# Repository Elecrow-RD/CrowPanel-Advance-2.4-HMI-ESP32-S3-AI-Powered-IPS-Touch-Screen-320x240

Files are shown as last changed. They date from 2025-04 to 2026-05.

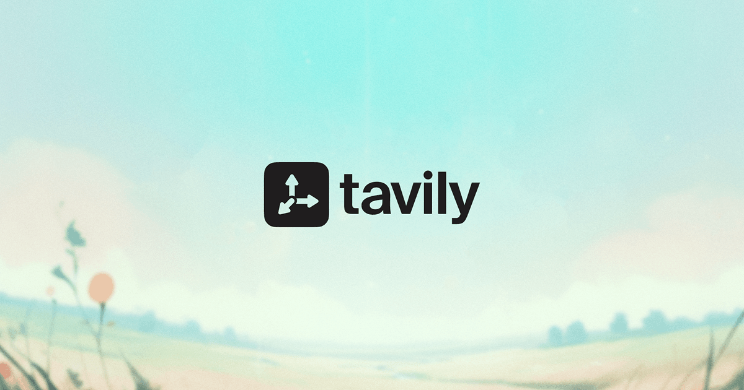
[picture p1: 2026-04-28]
example/V1.1_and_V1.2/Mimiclaw/mimiclaw/docs/tool-setup/images/tavily-og.png

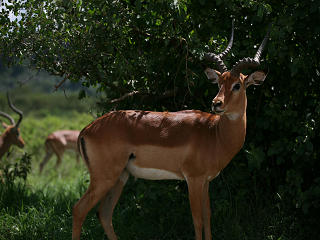
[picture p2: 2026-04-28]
example/V1.1_and_V1.2/ESP_IDF/Lesson05-SD_Images_24_28/picture_materials/2.bmp

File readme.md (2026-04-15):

## Menu
### 1, Product picture
### 2, Product version number
### 3, product information
### 4, Use the driver module
### 5,Quick Start
### 6,Folder structure.
### 7,Pin definition
### 8,Guidelines for downloading some of the files from the github repository

### 1, Product picture

ESP32 Advance HMI 2.4inch display

### 2, Product version number

| | Hardware | Software | Remark |
| ---- | --- | --- | --- |
| 1 | V1.0 | V1.0 | old |
| 1 | V1.1 | V1.1 | old |
| 1 | V1.2 | V1.2 | latest |

### Version update points:

**Version 1.1** 

V1.1 upgraded, optimized the amplifier circuit, better sound quality, and use IO21 to control mute. i2s_mic changed to two pins IO9 and IO10 control.

**Version 1.2** 

Only the button component has been updated. All other hardware and I/O pins remain the same as in the previous version.

### 3, product information

| Main Chip-**ESP32-S3-WROOM-1-N16R8** | |
| --- | --- |
| CPU/SoC | high-performance Xtensa 32-bit LX7 dual-core processor, with a  up to 240MHz |
| System Memory | 512KB SRAM、8M PSRAM |
| Memory | 16M Flash，384KB ROM |
| Development Language | MicroPython、C/C++ |
| Development Environment | ESP-IDF、Arduino IDE、LVGL、PlatformIO、MicroPython |
| **Screen** | |
| Size | 2.4 inch |
| Diver IC | ST7789 |
| Resolution | 800*480 |
| Display Panel | IPS Panel |
| Touch Panel | Capacitive Single Touch |
| Viewing Angle | 178° |
| Brightness | 400 cd/m²(Typ.) |
| Color Depth | 16-bit |
| **Wireless Communication - Onboard Antenna** | |
| WiFi | Support 2.4GHz, 802.11a/b/g/n |
| Bluetooth | Support Bluetooth 5.0 and BLE |
| Other | **Zigbee、nRF2401、Matter、Thread and Wi-Fi 6 (Optional)** |
| **Interface/Function** | |
| Interface | USB port, UART, I2C, SD card slot, battery socket, speaker port, microphone, etc. |
| Function | Audio amplifier, volume control, battery charge management, USB to UART, etc. |
| **Button/LED Indicator** | |
| Reset Button | Yes, press to reset device |
| Boot Button | Yes, press and hold the power button to burn the program |
| PWR | Power indicator |
| CHG | Lithium battery charging status, completion indication |
| **Other** | |
| Installation method | Back hanging, fixed hole |
| Operating temperature | -20~70 °C |
| Storage temperature | -30~80 °C |
| Power Input | 5V/2A, USB or UART terminal |
| Dimensions | 77.1*51.8*15.8*mm |

### 4, Use the driver module

| Name | dependency library |
| --- | --- |
| LVGL | lvgl/lvgl@8.3.3 |
| ST7789 | Adafruit GFX Library<br/>version=1.11.0 |

### 5,Quick Start

### Arduino IDE starts

#### Teaching Case Path：./example/example_code2.4

1.Download the library files used by this product to the 'libraries' folder.

C:\Users\Documents\Arduino\libraries\



2.Open the Arduino IDE



3.Open the code configuration environment and burn it



### ESP-IDF starts

#### Teaching Case Path：./example/idf_code

1.Right-click on an empty space in the project folder and select "Open with VS Code" to open the project.


2.In the IDF plug-in, select the port, then compile and flash


### 6,Folder structure.

|--3D file： Contains 3D model files (.stp) for the hardware. These files can be used for visualization, enclosure design, or integration into CAD software.

|--Datasheet: Includes datasheets for components used in the project, providing detailed specifications, electrical characteristics, and pin configurations.

|--Eagle_SCH&PCB: Contains **Eagle CAD** schematic (`.sch`) and PCB layout (`.brd`) files. These are used for circuit design and PCB manufacturing.

|--example: Provides example code and projects to demonstrate how to use the hardware and libraries. These examples help users get started quickly.

|--factory_firmware: Stores pre-compiled factory firmware that can be directly flashed onto the device. This ensures the device runs the default functionality.

|--factory_sourcecode:  Contains the source code for the factory firmware, allowing users to modify and rebuild the firmware as needed.

|--libraries: Includes necessary libraries required for compiling and running the project. These libraries provide drivers and additional functionalities for the hardware.

|--Squareline_studio Instructions for use: Squareline_studio instructions: Demonstrate the use of squareline studio.

### 7,Pin definition

#define SD_MOSI 6
#define SD_MISO 4
#define SD_SCK 5
#define SD_CS 7 

cfg.pin_sclk = 42;  // SPI、SCLK

cfg.pin_mosi = 39;  // SPI、CLK

cfg.pin_miso = -1;  // SPI、MISO

cfg.pin_dc = 41; 

#define TOUCH_GT911_SCL 16

#define TOUCH_GT911_SDA 15

### 8,Guidelines for downloading some of the files from the github repository

##### 1, open the link in your browser: https://downgit.github.io/

##### 2, paste the URL of the GitHub destination folder in the input box (example format: `https://github.com/username/repository name/tree/branch name/folder path`)

github_download1

##### 3, even a that way to download the file.

①Click the “Create Download Link” button to create a download link, copy the link and open it with your browser to download the contents of the corresponding folder directly.

github_download2

②Click Download, and you can also download it directly.

github_download3

#### Note: DownGit downloads are stored by default in **your browser's default downloads folder**, usually:

- **Windows**: `C:\Users\your username\Downloads\` (downloads folder)
- **macOS**: `~/Downloads/` (downloads folder)
- **Linux**: `~/Downloads/` (Downloads folder)

If you change the default download path in your browser, the file will be stored in the download location you set. You can find the downloaded file path in your browser's **Download History** (shortcut `Ctrl + J` or `Cmd + J`).

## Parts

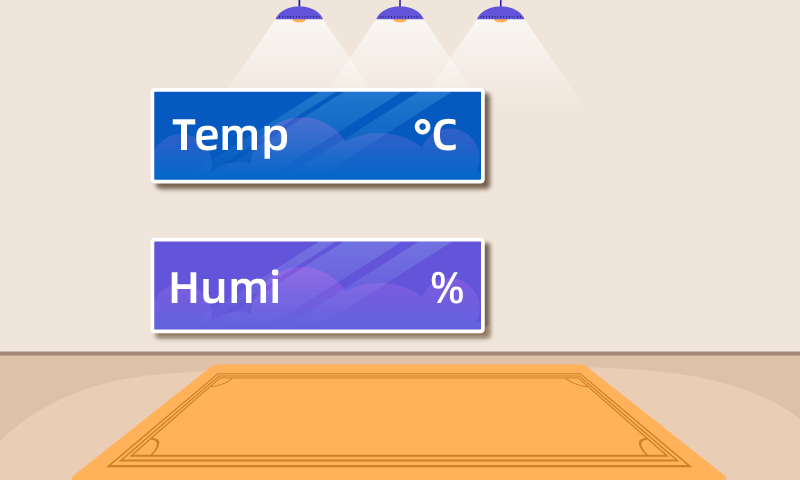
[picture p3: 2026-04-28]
example/V1.0/Arduino_Code/lesson-05/source material/800x480/background.png

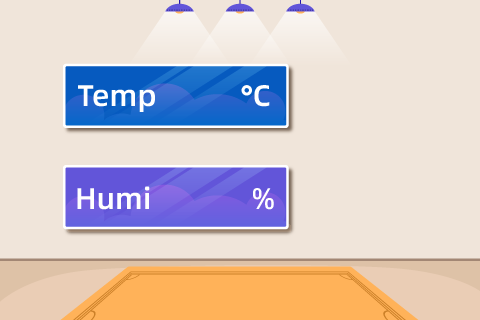
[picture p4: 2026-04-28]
example/V1.0/Arduino_Code/lesson-05/source material/480x320/background.png

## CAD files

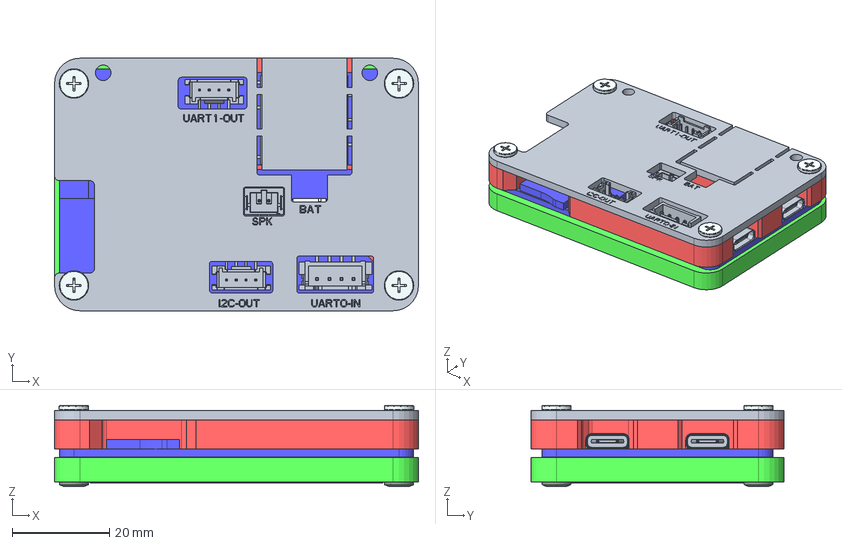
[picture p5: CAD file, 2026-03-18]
3D file/advance-hmi2_4-20260126.stp
74.8 x 51.9 x 16.7 mm
ESP32_DISPLAY_2_4_INCH_V1_0_15
GROVE_12_11
PRT0003_11
BOSS-EXTRUDE7_4__1_1_4_1_5
BOSS-EXTRUDE7_5__1_1_4_1_5
BOSS-EXTRUDE7_8__1_1_4_1_5
BOSS-EXTRUDE7_3__1_1_4_1_5
BOSS-EXTRUDE7_7__1_1_4_1_5
BOSS-EXTRUDE14_4__1_1_4_1_5
BOSS-EXTRUDE14_2__1_1_4_1_5
BOSS-EXTRUDE14_8__1_1_4_1_5
BOSS-EXTRUDE14_5__1_1_4_1_5
BOSS-EXTRUDE7_6__1_1_4_1_5
CUT-EXTRUDE5_1_1_4_1_5
MIRROR2_1_1_4_1_5
BOSS-EXTRUDE7_1__1_1_4_1_5
BOSS-EXTRUDE14_10__1_1_4_1_5
BOSS-EXTRUDE14_11__1_1_4_1_5
BOSS-EXTRUDE14_9__1_1_4_1_5
BOSS-EXTRUDE14_6__1_1_4_1_5
BOSS-EXTRUDE14_12__1_1_4_1_5
BOSS-EXTRUDE14_3__1_1_4_1_5
BOSS-EXTRUDE14_7__1_1_4_1_5
BOSS-EXTRUDE7_9__1_1_4_1_5
BOSS-EXTRUDE7_2__1_1_4_1_5
BOSS-EXTRUDE7_4__1_1_1_1_4_8_5
BOSS-EXTRUDE7_5__1_1_1_1_4_8_5
BOSS-EXTRUDE7_8__1_1_1_1_4_8_5
BOSS-EXTRUDE7_3__1_1_1_1_4_8_5
BOSS-EXTRUDE7_7__1_1_1_1_4_8_5
BOSS-EXTRUDE14_4__1_1_1_1_4_8_5
BOSS-EXTRUDE14_2__1_1_1_1_4_8_5
BOSS-EXTRUDE14_8__1_1_1_1_4_8_5
BOSS-EXTRUDE14_5__1_1_1_1_4_8_5
BOSS-EXTRUDE7_6__1_1_1_1_4_8_5
CUT-EXTRUDE5_1_1_1_1_4_8_5
MIRROR2_1_1_1_1_4_8_5
BOSS-EXTRUDE7_1__1_1_1_1_4_8_5
BOSS-EXTRUDE14_10__1_1_1_1_4_8_
BOSS-EXTRUDE14_11__1_1_1_1_4_8_
BOSS-EXTRUDE14_9__1_1_1_1_4_8_5
BOSS-EXTRUDE14_6__1_1_1_1_4_8_5
BOSS-EXTRUDE14_12__1_1_1_1_4_8_
BOSS-EXTRUDE14_3__1_1_1_1_4_8_5
BOSS-EXTRUDE14_7__1_1_1_1_4_8_5
BOSS-EXTRUDE7_9__1_1_1_1_4_8_5
BOSS-EXTRUDE7_2__1_1_1_1_4_8_5
7-PIN_11
PRT0004_11
XK-00_28
SK22_26
DG-01_18
PRT0006_26
ZM_M3_12 x 4
ZM_M2_5 x 4

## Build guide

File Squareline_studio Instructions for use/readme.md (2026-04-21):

# Use SquareLine Studio and LVGL libraries to create a UI interface to light the lights

## **1.** Introduce LVGL

------

LVGL (LittlevGL) is an open-source, lightweight, high-performance embedded graphics library designed specifically for devices with limited resources. It supports multi platform porting, provides rich controls, animations, touch support, and highly customizable styles, suitable for fields such as smart homes, industrial equipment, medical instruments, etc. LVGL is centered around modular design and can run on bare metal or operating systems, accelerating GUI development through powerful community support and tools such as SquareLine Studio.



SquareLine Studio is a next-generation user interface (UI) solution for individuals and professionals, allowing users to quickly and easily design and develop aesthetically pleasing UI for embedded devices. This software provides integrated design, prototyping, and development capabilities, supporting the export of platform independent C or MicroPython code for LVGL (Lightweight Graphics Library), which can be compiled and run on any vendor's device.



## 2.Install SquareLine Studio

------

### **2.1** Installation Guide

Enter the https://squareline.io/ to download the SquareLine installation file.



Download the version 1.4.0



Double-click the setup.exe file.



Click install.



Wait for installation.



Installation finish.



There is a 30-day trial period for the first time you use it. Please follow the prompts to register an account. You will continue to use it when you log in to your account next time.



### **2.2** Software Function Introduction

Open the software

The historical project page: open the project built earlier.



Create a project page: choose different platforms according to different hardware of the project.



###### When select the Arduino framwork, there's only one option "Arduino with TFT_eSPI". By choosing this, the squareline studio will generate a template code suitable for the TFT_eSPI library. However, squareline studio not only supports the TFT_eSPI library, it supports a variety of libraries to suit different hardware and application needs. For example, Adafruit_GFX library, LovyanGFX etc.[¶](https://www.elecrow.com/pub/wiki/2.4_3_Use_LVGL_library_to_create_UI_interface_and_light_up_lights.html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)

###### After using SLS to generate UI code, we then use different graphics libraries according to different hardware and modify the corresponding code to display the content you design.[¶](https://www.elecrow.com/pub/wiki/2.4_3_Use_LVGL_library_to_create_UI_interface_and_light_up_lights.html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)

Example page. This page has several official examples for reference.



The project settings bar is used to make basic settings for the project, including property settings such as project name, screen size, display angle, etc.



###### Note： Please select the corresponding resolution and color depth according to the screen specifications.[¶](https://www.elecrow.com/pub/wiki/2.4_3_Use_LVGL_library_to_create_UI_interface_and_light_up_lights.html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)



##### ①Toolbar, including File, Export, and Help. Basic file operation bar, create or open files, export UI files and other operations. Click help and there are related introductory documents.

##### ②Screen bar, the project screen will be listed here.

##### ③Widget area, all widgets are here and can be selected and used according to project needs.

##### ④Hierarchy area, it will show every widget used in each screen.

##### ⑤This area shows the actual display effect, you can adjust the widgets or screen here.

##### ⑥Material column, the added materials are displayed here.

##### ⑦Setting bar, where you can make basic settings for each part, including the basic attributes and trigger operations of the part.

##### ⑧Theme bar, different themes can be set.

## 3 Use SquareLine Studio to create UI control interfaces

------

Firstly, open the SquareLine Studio software and create a case study



Choose the correct resolution based on the different sizes you are using



Here, I take a 2.4-inch screen as an example. After determining the resolution, I fill it in



After selecting the parameters, click Create



Open the photo of the desk lamp we provided and add it in. (Of course, you can also choose the image you want to use)





The lamp_28 image size is available for both 2.4-inch and 2.8-inch screens.

Table_lamp image sizes are available for 3.5-inch, 4.3-inch, 5.0-inch, and 7-inch screens.



After adding it, drag and drop the image in.



The task we need to complete is to turn on and off the lights by clicking on the buttons on the graphical interface. So we need to design two buttons

From the left sidebar, select Button and drag it into the interface.



You can adjust the border of the button with the mouse, which can adjust the size of the button, and you can also drag and drop the button to adjust its position.

Then, by selecting Background, choose the background color of the Button.





We have made the button patterns, and now we need to add labels to the button patterns in order to distinguish their functions.

Drag and drop from the left sidebar, select Label, and drag into the interface.



Modify the text content of the label



And modify the font size and text color of the text



The Button and Label have been designed. Click on the Hierarchy in the right-hand column and drag the Label onto the Button line to merge them into one.



At this point, if you drag the buttons again, you will find that they are dragged together

Next, we will copy a completed button, right-click, and paste it in.







Click the second button ON to change the text content to Off. Used to achieve the effect of turning off lights.



## **4** Add functions to the buttons to enable them to turn on and off lights

------

Select 'event' to add in the right sidebar



Select 'released' as the triggering condition and 'Call function' as the action.



After selecting, click ADD.

And add a function name to the CALL Function. (Customization is sufficient)



Similarly, add an event to the Off button. The operation process is the same as above.



After adding, run





## **5** UI interface design completed, exporting UI files for easy use in subsequent code

------

Click on Project Setting



Set export path





Complete the setup and export file



Copy and paste the exported code into the code folder we need to open





Then double-click 2_4LVGL.ino and open it using Arduino IDE

## **6 Connect the light bulb and add code to control the light bulb to turn on and off**

------

Connect the light bulb at the UART1 interface



Observing the schematic diagram of this size, it is known that the pin for UART1 to control the light bulb to turn on and off is 18





So in the code, set pin 18 as the output mode.

A large-sized screen requires setting 19 pins as the output mode.

The code for size 2.4 is the same as the code for size 3.5, only the UI display file configured is different



And add the function of turning on and off the light bulb in the ui_ event. c file.

(When the On button is clicked, the light is on; when the Off button is clicked, the light is off)



## **7 Configure the code running environment and upload the code**

------

(!! Before uploading the code, please use different library files according to the size you are using. You can review the content of Lesson 2)

(For large-sized screens of 4.3 inches, 5.0 inches, and 7.0 inches, be sure to switch the mode to 0 1 state before uploading the code, because the pins of UART1 and W-M mode are both used in 0 1 mode, so that you can use the pins of UART1)





So you can see the UI interface you just designed



You can click the On and Off buttons to control the on/off of the lights





## 8 Code presentation

------

### 2.4 inchs

```
#include "pins_config.h"
#include "LovyanGFX_Driver.h"
#include <lvgl.h>
#include <Arduino.h>
#include <Wire.h>
#include <SPI.h>
#include <stdbool.h>
#include <Adafruit_SSD1306.h>
#include <Adafruit_GFX.h>
#include "ui.h"

LGFX gfx;
/* Change to your screen resolution */
static lv_disp_draw_buf_t draw_buf;
static lv_color_t *buf;
static lv_color_t *buf1;
// Display refresh
void my_disp_flush(lv_disp_drv_t *disp, const lv_area_t *area, lv_color_t *color_p) {
  if (gfx.getStartCount() > 0) {
    gfx.endWrite();
  }
  gfx.pushImageDMA(area->x1, area->y1, area->x2 - area->x1 + 1, area->y2 - area->y1 + 1, (lgfx::rgb565_t *)&color_p->full);

  lv_disp_flush_ready(disp);  //Tell lvgl that the refresh is complete
}
uint16_t touchX, touchY;
void my_touchpad_read(lv_indev_drv_t *indev_driver, lv_indev_data_t *data)
{
  data->state = LV_INDEV_STATE_REL;
  if ( gfx.getTouch( &touchX, &touchY ) ) {
    data->state = LV_INDEV_STATE_PR;
    //Set coordinates (the Y-axis of the screen on Longxian is opposite, and the X-axis of the screen on Puyang is opposite)
    data->point.x = LCD_H_RES - touchX;
    data->point.y = touchY; //After rotation, the Y-axis is reversed
    Serial.print( "Data x " );
    Serial.println( data->point.x );
    Serial.print( "Data y " );
    Serial.println( data->point.y );
  }
}
void setup()
{
  Serial.begin(115200); 
  pinMode(18, OUTPUT);
  Wire.begin(15, 16);
  delay(50);
 //GT911 power on timing --->0x5D
  pinMode(1, OUTPUT);
  pinMode(2, OUTPUT);
  digitalWrite(1, LOW);
  digitalWrite(2, LOW);
  delay(20);
  digitalWrite(2, HIGH);
  delay(100);
  pinMode(1, INPUT);
  /*end*/

  // Init Display
  gfx.init();
  gfx.initDMA();
  gfx.startWrite();
  gfx.fillScreen(TFT_BLACK);

  lv_init();
  size_t buffer_size = sizeof(lv_color_t) * LCD_H_RES * LCD_V_RES;
  buf = (lv_color_t *)heap_caps_malloc(buffer_size, MALLOC_CAP_SPIRAM);
  buf1 = (lv_color_t *)heap_caps_malloc(buffer_size, MALLOC_CAP_SPIRAM);
  assert(buf);
  assert(buf1);
  lv_disp_draw_buf_init(&draw_buf, buf, buf1, LCD_H_RES * LCD_V_RES);

  //Initialize display
  static lv_disp_drv_t disp_drv;
  lv_disp_drv_init(&disp_drv);
  //Change the following lines to your display resolution
  disp_drv.hor_res = LCD_H_RES;
  disp_drv.ver_res = LCD_V_RES;
  disp_drv.flush_cb = my_disp_flush;
  disp_drv.draw_buf = &draw_buf;
  lv_disp_drv_register(&disp_drv);

  //Initialize input device driver program
  static lv_indev_drv_t indev_drv;
  lv_indev_drv_init(&indev_drv);
  indev_drv.type = LV_INDEV_TYPE_POINTER;
  indev_drv.read_cb = my_touchpad_read;
  lv_indev_drv_register(&indev_drv);
  delay(100);

  /* Turn on backlight */
  pinMode(38, OUTPUT);
  digitalWrite(38, HIGH);

  // Init touch device
  // gt911_address = 0x5D;
  // touch_init(gt911_address);

  gfx.fillScreen(TFT_BLACK);
  // lv_demo_widgets();
  ui_init();
  Serial.println( "Setup done" );
}
void loop()
{
  lv_timer_handler(); /* let the GUI do its work */
  delay(5);
}
```

**If your code compiles incorrectly, you can check if the ESP32 version number is correct. The ESP32 version number we need for this lesson is 3.0.2.**

new-1

**Secondly, please pay attention to replacing the corresponding size library file.**

**Select the appropriate library file based on the product screen size**

Path reference：C:\ESP32_Code\CrowPanel_Advanced_HMI\Arduino_lib Series Library

new-2

**I will use the Advance 7.0-inch product as an example for operation**

Copy the Libraries Advanced 7.0 folder

Open Arduino IDE runtime library file path

Reference path: C:\Users\14175\Documents\Arduino

new-3

Delete the existing libraries folder

new-4

Paste the copied library Advanced 7.0 folder into this path

new-5

Change the folder name to the original libraries

new-6

Library update completed, restart Arduino IDE.

**When using other sizes, changing the library file is the same operation**

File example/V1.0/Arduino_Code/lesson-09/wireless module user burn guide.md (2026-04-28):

## Wirless Module H2/C6 Single Board Burn-in Method

### 1.Tools to be prepared

| | Tools | quantities |
| ---- | --- | --- |
| 1 | Single Female DuPont Cable | 4 |
| 2 | Serial Module Tools | 1 |
| 3 | Wirless Module H2/C6 | 1 |
| 4 | Soldering Iron & Wire | |

 Single Female DuPont Cable
 


Wirless Module H2/C6



Serial modules (CH340/CP2102, etc. are fine)



### 2.Weld line.

The burn-in pins for the Wirless Module H2/C6 are the same, and the four wires that need to be soldered are located as follows：

（Arrow pointing up）

| RX | TX |
| ---- | ---- |
| | |
| | |
| | |
| 3V3  | |
| GND  | |
| | |

Module Pin Definition

The finished soldering is shown below.





### 3.Burning

RX is connected to TX of the serial module;

TX connection to the RX of the serial module;

3V3 connection to the 3V3 of the serial module;

GND connection to the GND of the serial module.

Connect the serial module to the computer and find the corresponding serial device number (e.g. COM7) in the Task Manager.



Open Arduino or open the corresponding serial port under any serial port tool.



Press and hold the BOOT key and then press the RST key to enter burn mode.



The serial monitor prints to enter burn-in mode.


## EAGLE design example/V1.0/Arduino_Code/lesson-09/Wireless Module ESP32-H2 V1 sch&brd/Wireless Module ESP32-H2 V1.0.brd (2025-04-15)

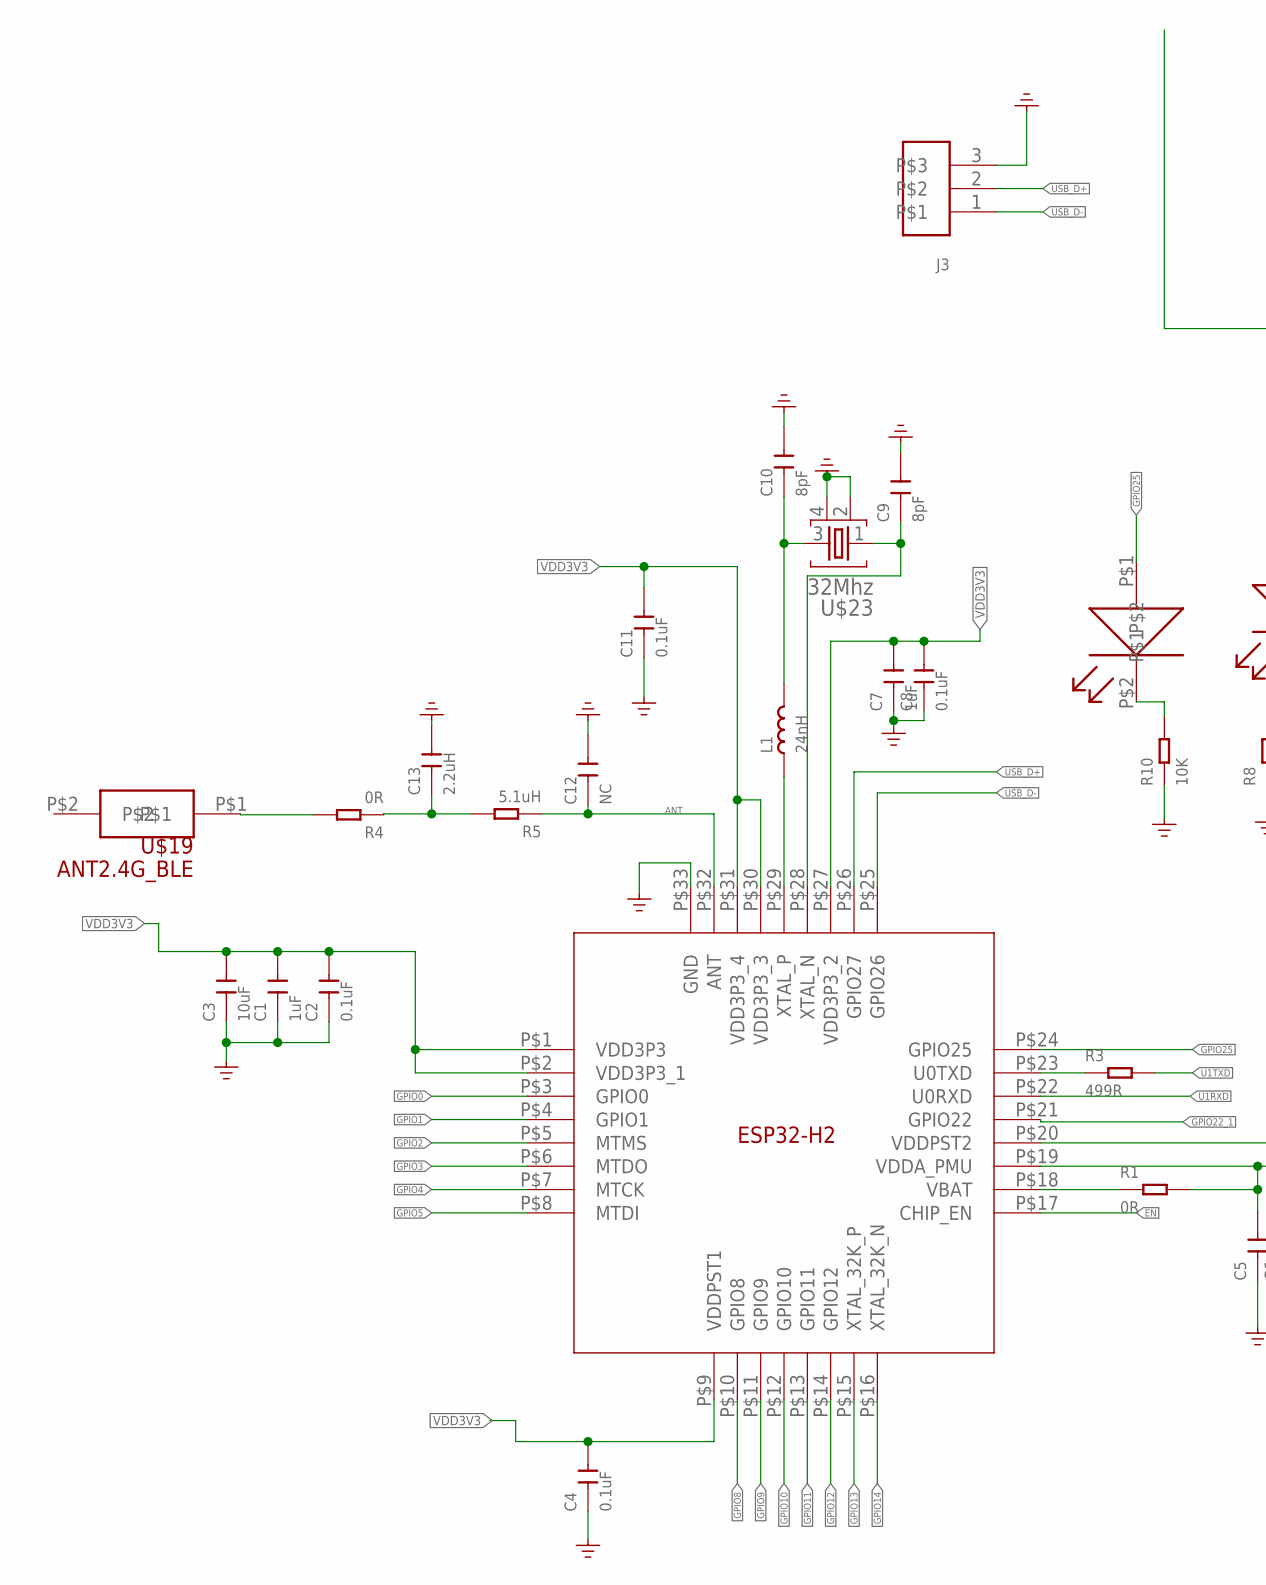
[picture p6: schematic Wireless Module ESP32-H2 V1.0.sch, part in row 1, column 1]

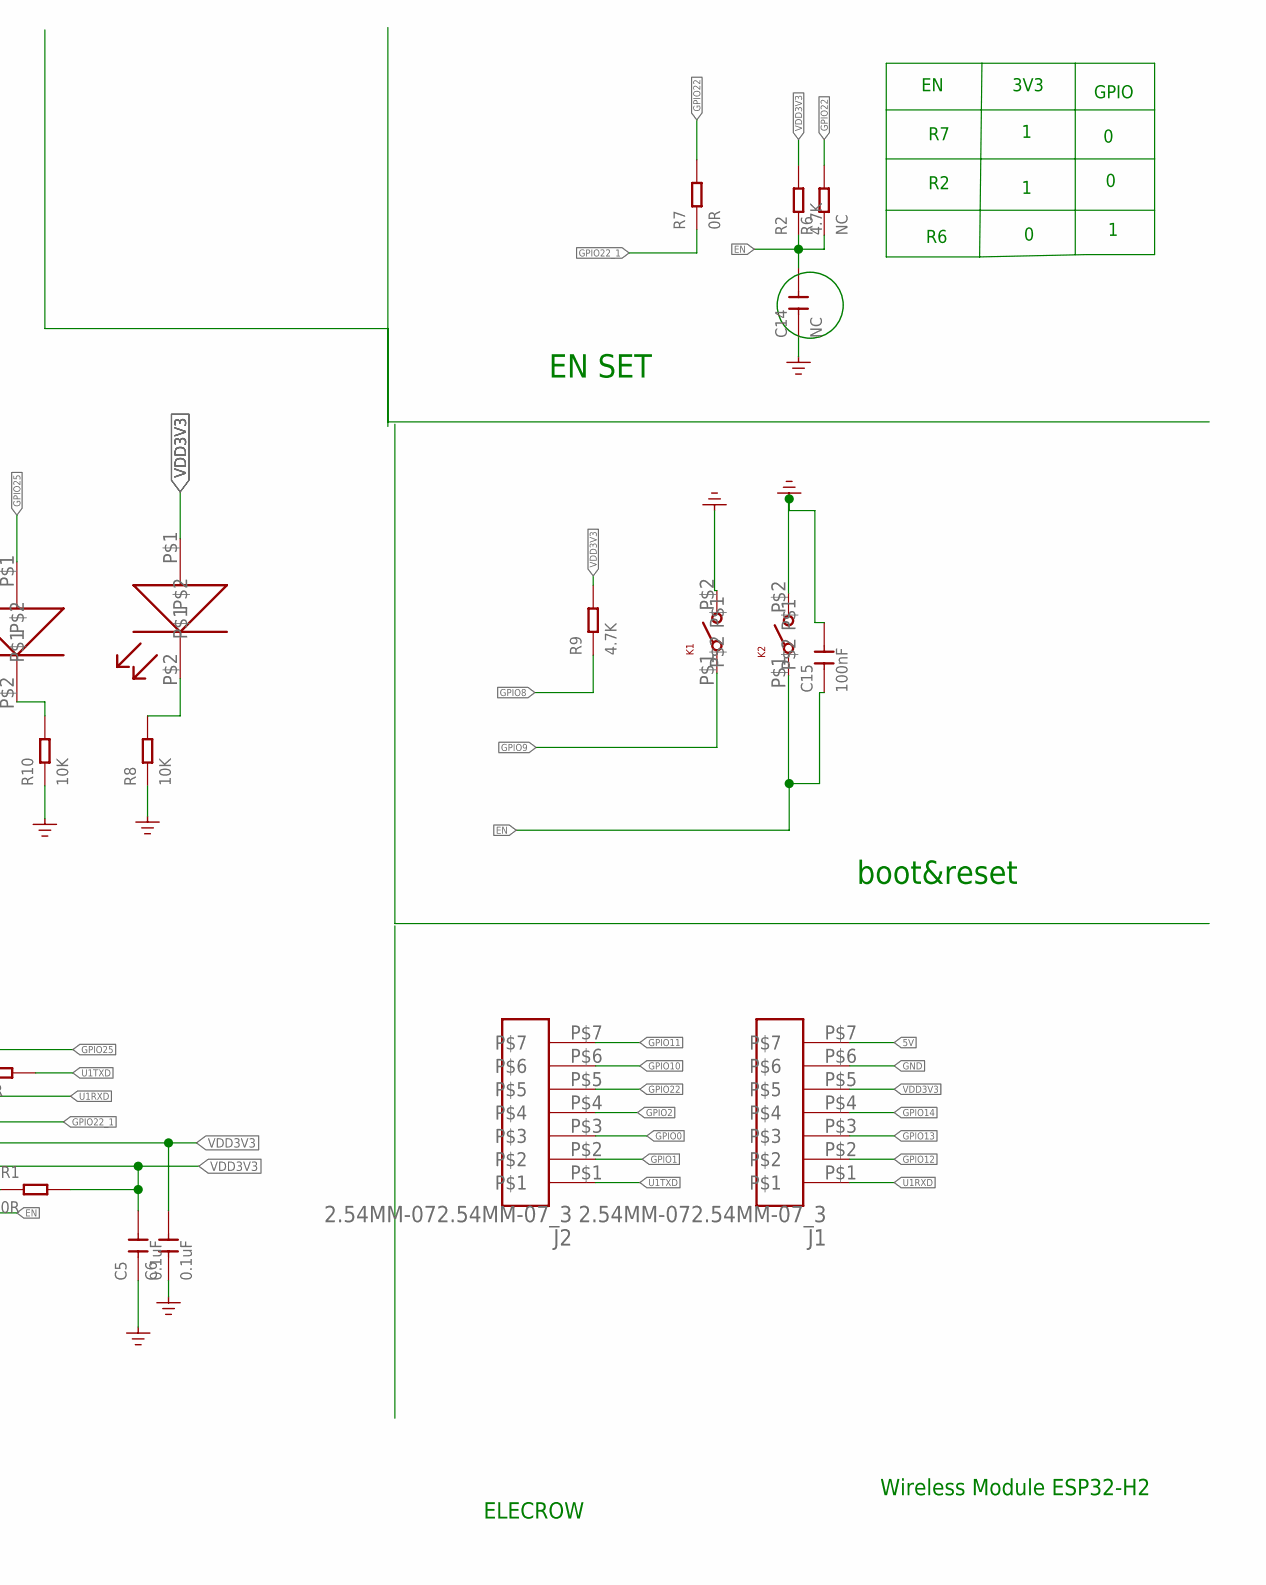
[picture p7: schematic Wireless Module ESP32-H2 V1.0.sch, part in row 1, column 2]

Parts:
C1, C7: 1uF; DISCRETE-NEW_C0402
C2, C4, C5, C6, C8, C11: 0.1uF; DISCRETE-NEW_C0402
C3: 10uF; DISCRETE-NEW_C0402
C9, C10: 8pF; DISCRETE-NEW_C0402
C12, C14: NC; DISCRETE-NEW_C0402
C13: 2.2uH; DISCRETE-NEW_C0402
C15: 100nF; DISCRETE-NEW_C0402
J1, J2: 2.54MM-072.54MM-07_3; 2.54MM-07_3
J3: 1.27MM-3P
K1, K2: KEY_SMD; KEY_3*2.5
L1: 24nH; DISCRETE-NEW_L0402
LED1, LED2: LED_SMT; LED_0402
R1, R4, R7: 0R; DISCRETE-NEW_R0402
R2, R9: 4.7K; DISCRETE-NEW_R0402
R3: 499R; DISCRETE-NEW_R0402
R5: 5.1uH; DISCRETE-NEW_R0402
R6: NC; DISCRETE-NEW_R0402
R8, R10: 10K; DISCRETE-NEW_R0402
U$1: ESP32-H2
U$19: ANT2.4G_BLE; 2.4G_BLE
U$23: 32Mhz; NORDIC_NRF_BT-XTAL_2016_N

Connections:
5V: J1.P$7
ANT: C12.1, R5.1, U$1.P$32 (ANT)
EN: C14.2, C15.1, K2.P$1, R2.1, R6.1, U$1.P$17 (CHIP_EN)
GND: C1.1, C2.1, C3.1, C4.1, C5.1, C6.1, C7.1, C8.1, C9.2, C10.2, C11.1, C12.2, C13.2, C14.1, C15.2, J1.P$6, J3.3, K1.P$2, K2.P$2, R8.1, R10.1, U$1.P$33 (GND), U$23.2, U$23.4
GPIO0: J2.P$3, U$1.P$3 (GPIO0)
GPIO1: J2.P$2, U$1.P$4 (GPIO1)
GPIO2: J2.P$4, U$1.P$5 (MTMS)
GPIO3: U$1.P$6 (MTDO)
GPIO4: U$1.P$7 (MTCK)
GPIO5: U$1.P$8 (MTDI)
GPIO8: R9.1, U$1.P$10 (GPIO8)
GPIO9: K1.P$1, U$1.P$11 (GPIO9)
GPIO10: J2.P$6, U$1.P$12 (GPIO10)
GPIO11: J2.P$7, U$1.P$13 (GPIO11)
GPIO12: J1.P$2, U$1.P$14 (GPIO12)
GPIO13: J1.P$3, U$1.P$15 (XTAL_32K_P)
GPIO14: J1.P$4, U$1.P$16 (XTAL_32K_N)
GPIO22: J2.P$5, R6.2, R7.2
GPIO22_1: R7.1, U$1.P$21 (GPIO22)
GPIO25: LED1.P$1, U$1.P$24 (GPIO25)
unnamed: C13.1, R4.1, R5.2
unnamed: R3.1, U$1.P$23 (U0TXD)
unnamed: C10.1, L1.2, U$23.3
unnamed: C9.1, U$1.P$28 (XTAL_N), U$23.1
unnamed: LED2.P$2, R8.2
unnamed: LED1.P$2, R10.2
unnamed: R4.2, U$19.P$1
unnamed: L1.1, U$1.P$29 (XTAL_P)
P$18: R1.1, U$1.P$18 (VBAT)
U1RXD: J1.P$1, U$1.P$22 (U0RXD)
U1TXD: J2.P$1, R3.2
USB_D+: J3.2, U$1.P$26 (GPIO27)
USB_D-: J3.1, U$1.P$25 (GPIO26)
VDD3V3: C1.2, C2.2, C3.2, C4.2, C5.2, C6.2, C7.2, C8.2, C11.2, J1.P$5, LED2.P$1, R1.2, R2.2, R9.2, U$1.P$1 (VDD3P3), U$1.P$2 (VDD3P3_1), U$1.P$9 (VDDPST1), U$1.P$19 (VDDA_PMU), U$1.P$20 (VDDPST2), U$1.P$27 (VDD3P3_2), U$1.P$30 (VDD3P3_3), U$1.P$31 (VDD3P3_4)

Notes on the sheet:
3V3
GPIO
EN SET
boot&reset
ELECROW
Wireless Module ESP32-H2

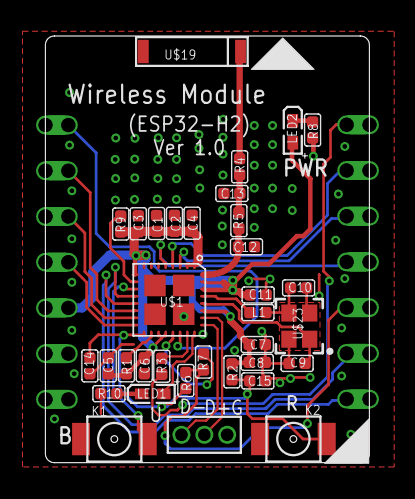
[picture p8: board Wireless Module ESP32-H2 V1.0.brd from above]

Board: 2 copper layers, 18.0 x 23.7 mm, 36 parts (0 on the bottom side), 30 nets.

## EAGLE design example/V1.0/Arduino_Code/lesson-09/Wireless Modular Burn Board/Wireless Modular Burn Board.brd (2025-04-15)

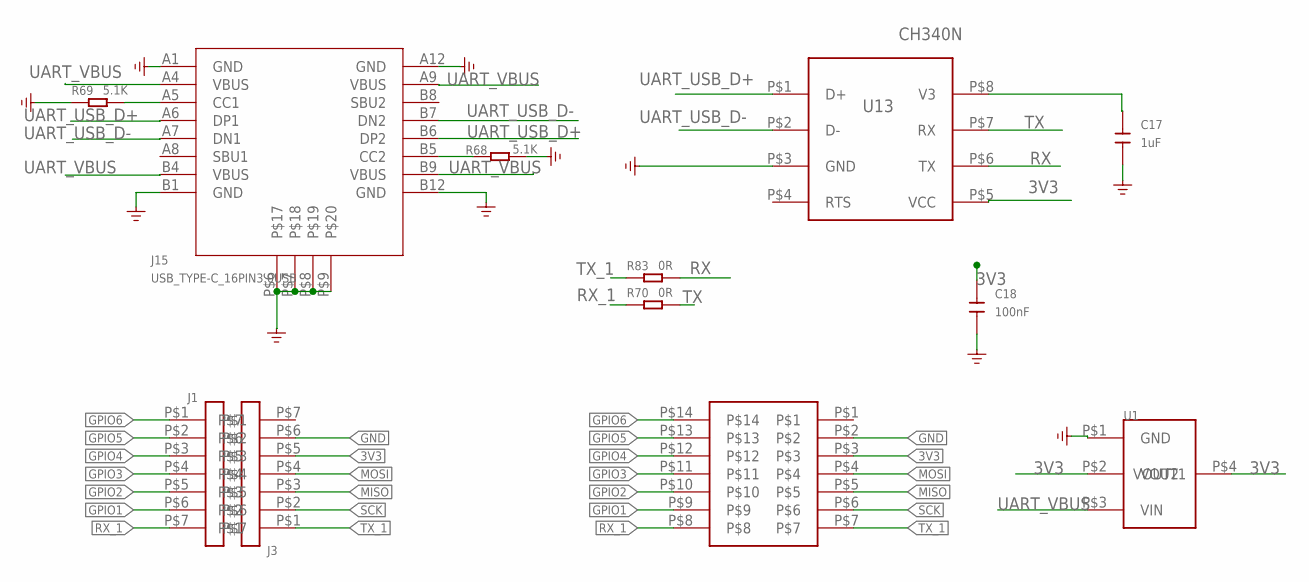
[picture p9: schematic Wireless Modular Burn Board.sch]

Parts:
C17: 1uF; 0603
C18: 100nF; 0603
J1, J3: 2.54MM-7P
J2: SMT-2.54MM-7P
J15: USB_TYPE-C_16PIN3.0USB; KEVIN_3.0TYPEC-SMD
R68, R69: 5.1K; DISCRETE_R0603
R70, R83: 0R; DISCRETE_R0603
U1: AMS1117-3V3; SOT-223
U13: CH340N; SOP8

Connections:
3V3: C18.2, J2.P$3, J3.P$5, U1.P$2 (VOUT1), U1.P$4 (VOUT2), U13.P$5 (VCC)
GND: C17.1, C18.1, J2.P$2, J3.P$6, J15.A1 (GND), J15.A12 (GND), J15.B1 (GND), J15.B12 (GND), J15.P$6, J15.P$7, J15.P$8, J15.P$9, R68.2, R69.1, U1.P$1 (GND), U13.P$3 (GND)
GPIO1: J1.P$6, J2.P$9
GPIO2: J1.P$5, J2.P$10
GPIO3: J1.P$4, J2.P$11
GPIO4: J1.P$3, J2.P$12
GPIO5: J1.P$2, J2.P$13
GPIO6: J1.P$1, J2.P$14
MISO: J2.P$5, J3.P$3
MOSI: J2.P$4, J3.P$4
unnamed: J15.B5 (CC2), R68.1
unnamed: J15.A5 (CC1), R69.2
unnamed: C17.2, U13.P$8 (V3)
RX: R83.2, U13.P$6 (TX)
RX_1: J1.P$7, J2.P$8, R70.1
SCK: J2.P$6, J3.P$2
TX: R70.2, U13.P$7 (RX)
TX_1: J2.P$7, J3.P$1, R83.1
UART_USB_D+: J15.A6 (DP1), J15.B6 (DP2), U13.P$1 (D+)
UART_USB_D-: J15.A7 (DN1), J15.B7 (DN2), U13.P$2 (D-)
UART_VBUS: J15.A4 (VBUS), J15.A9 (VBUS), J15.B4 (VBUS), J15.B9 (VBUS), U1.P$3 (VIN)

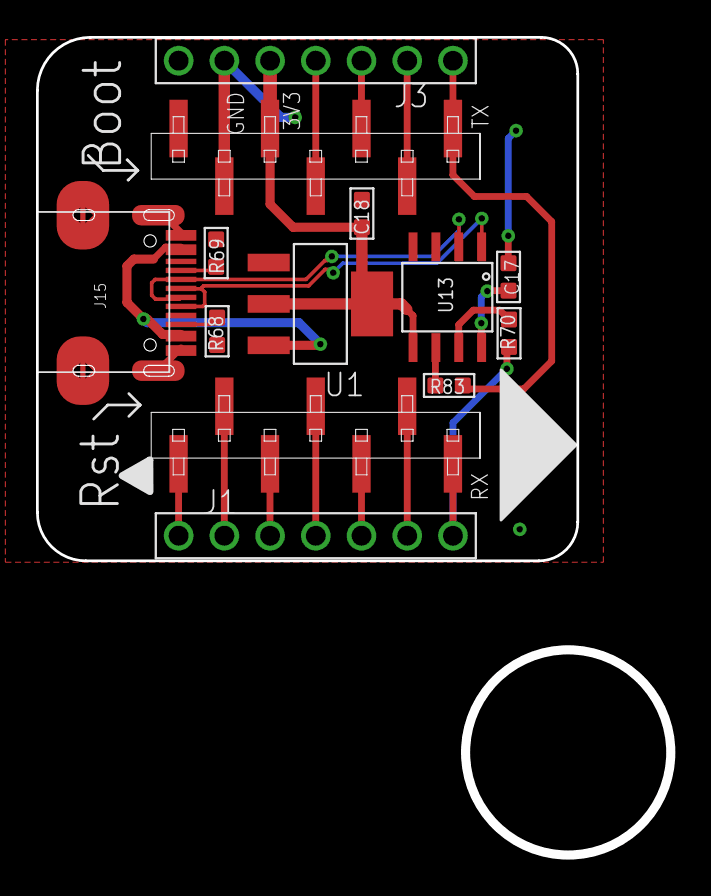
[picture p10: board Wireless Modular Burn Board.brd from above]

Board: 2 copper layers, 30.0 x 29.1 mm, 12 parts (0 on the bottom side), 21 nets.

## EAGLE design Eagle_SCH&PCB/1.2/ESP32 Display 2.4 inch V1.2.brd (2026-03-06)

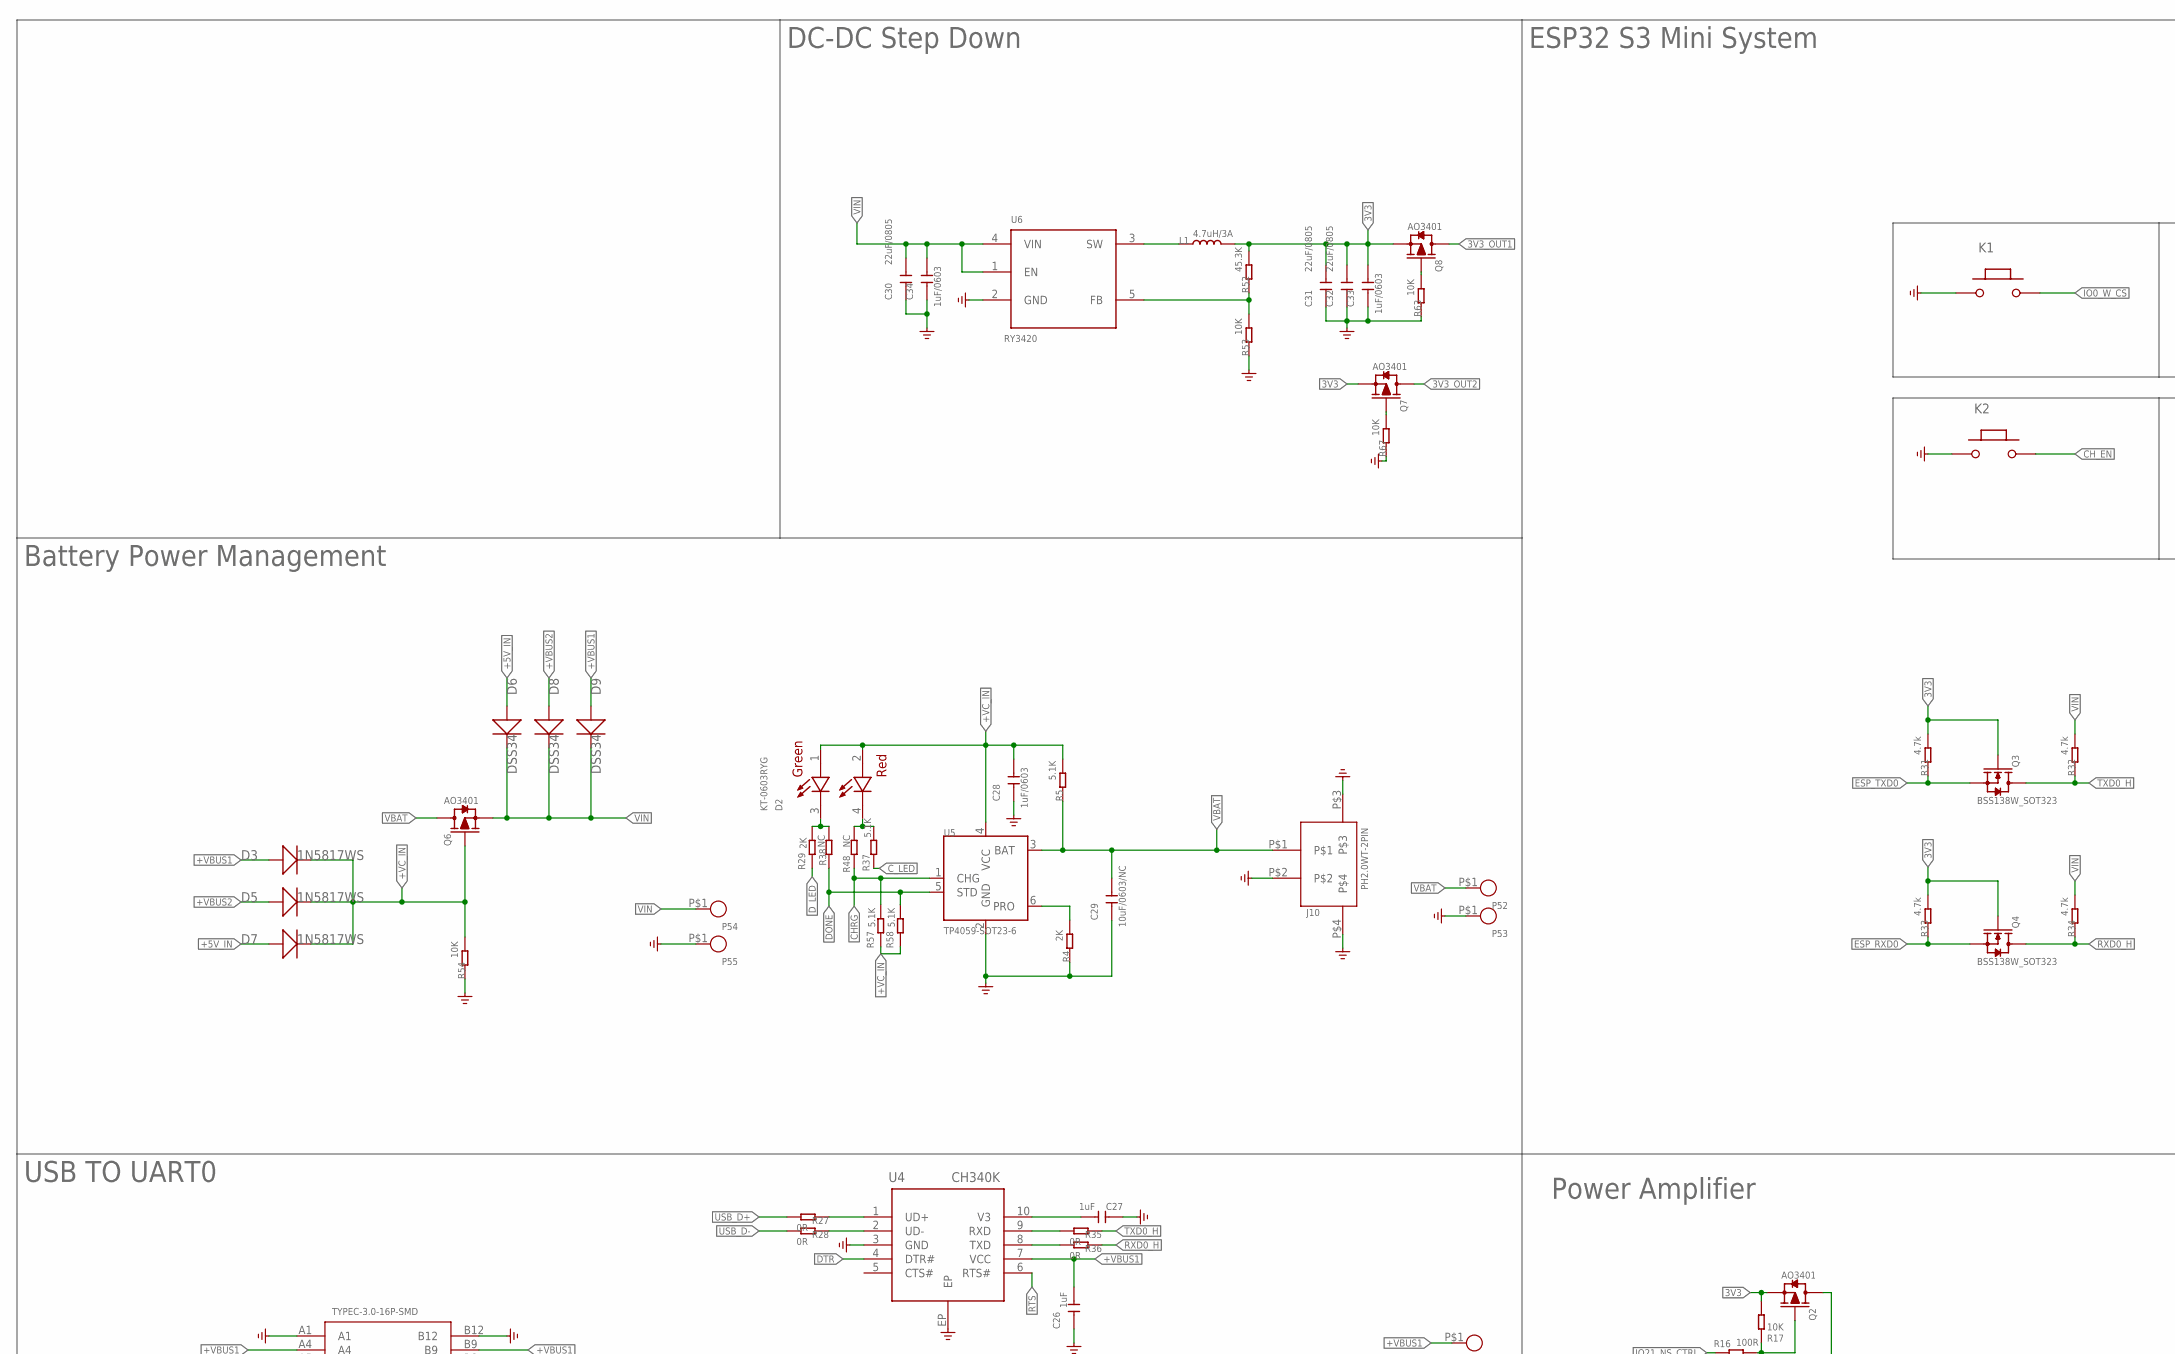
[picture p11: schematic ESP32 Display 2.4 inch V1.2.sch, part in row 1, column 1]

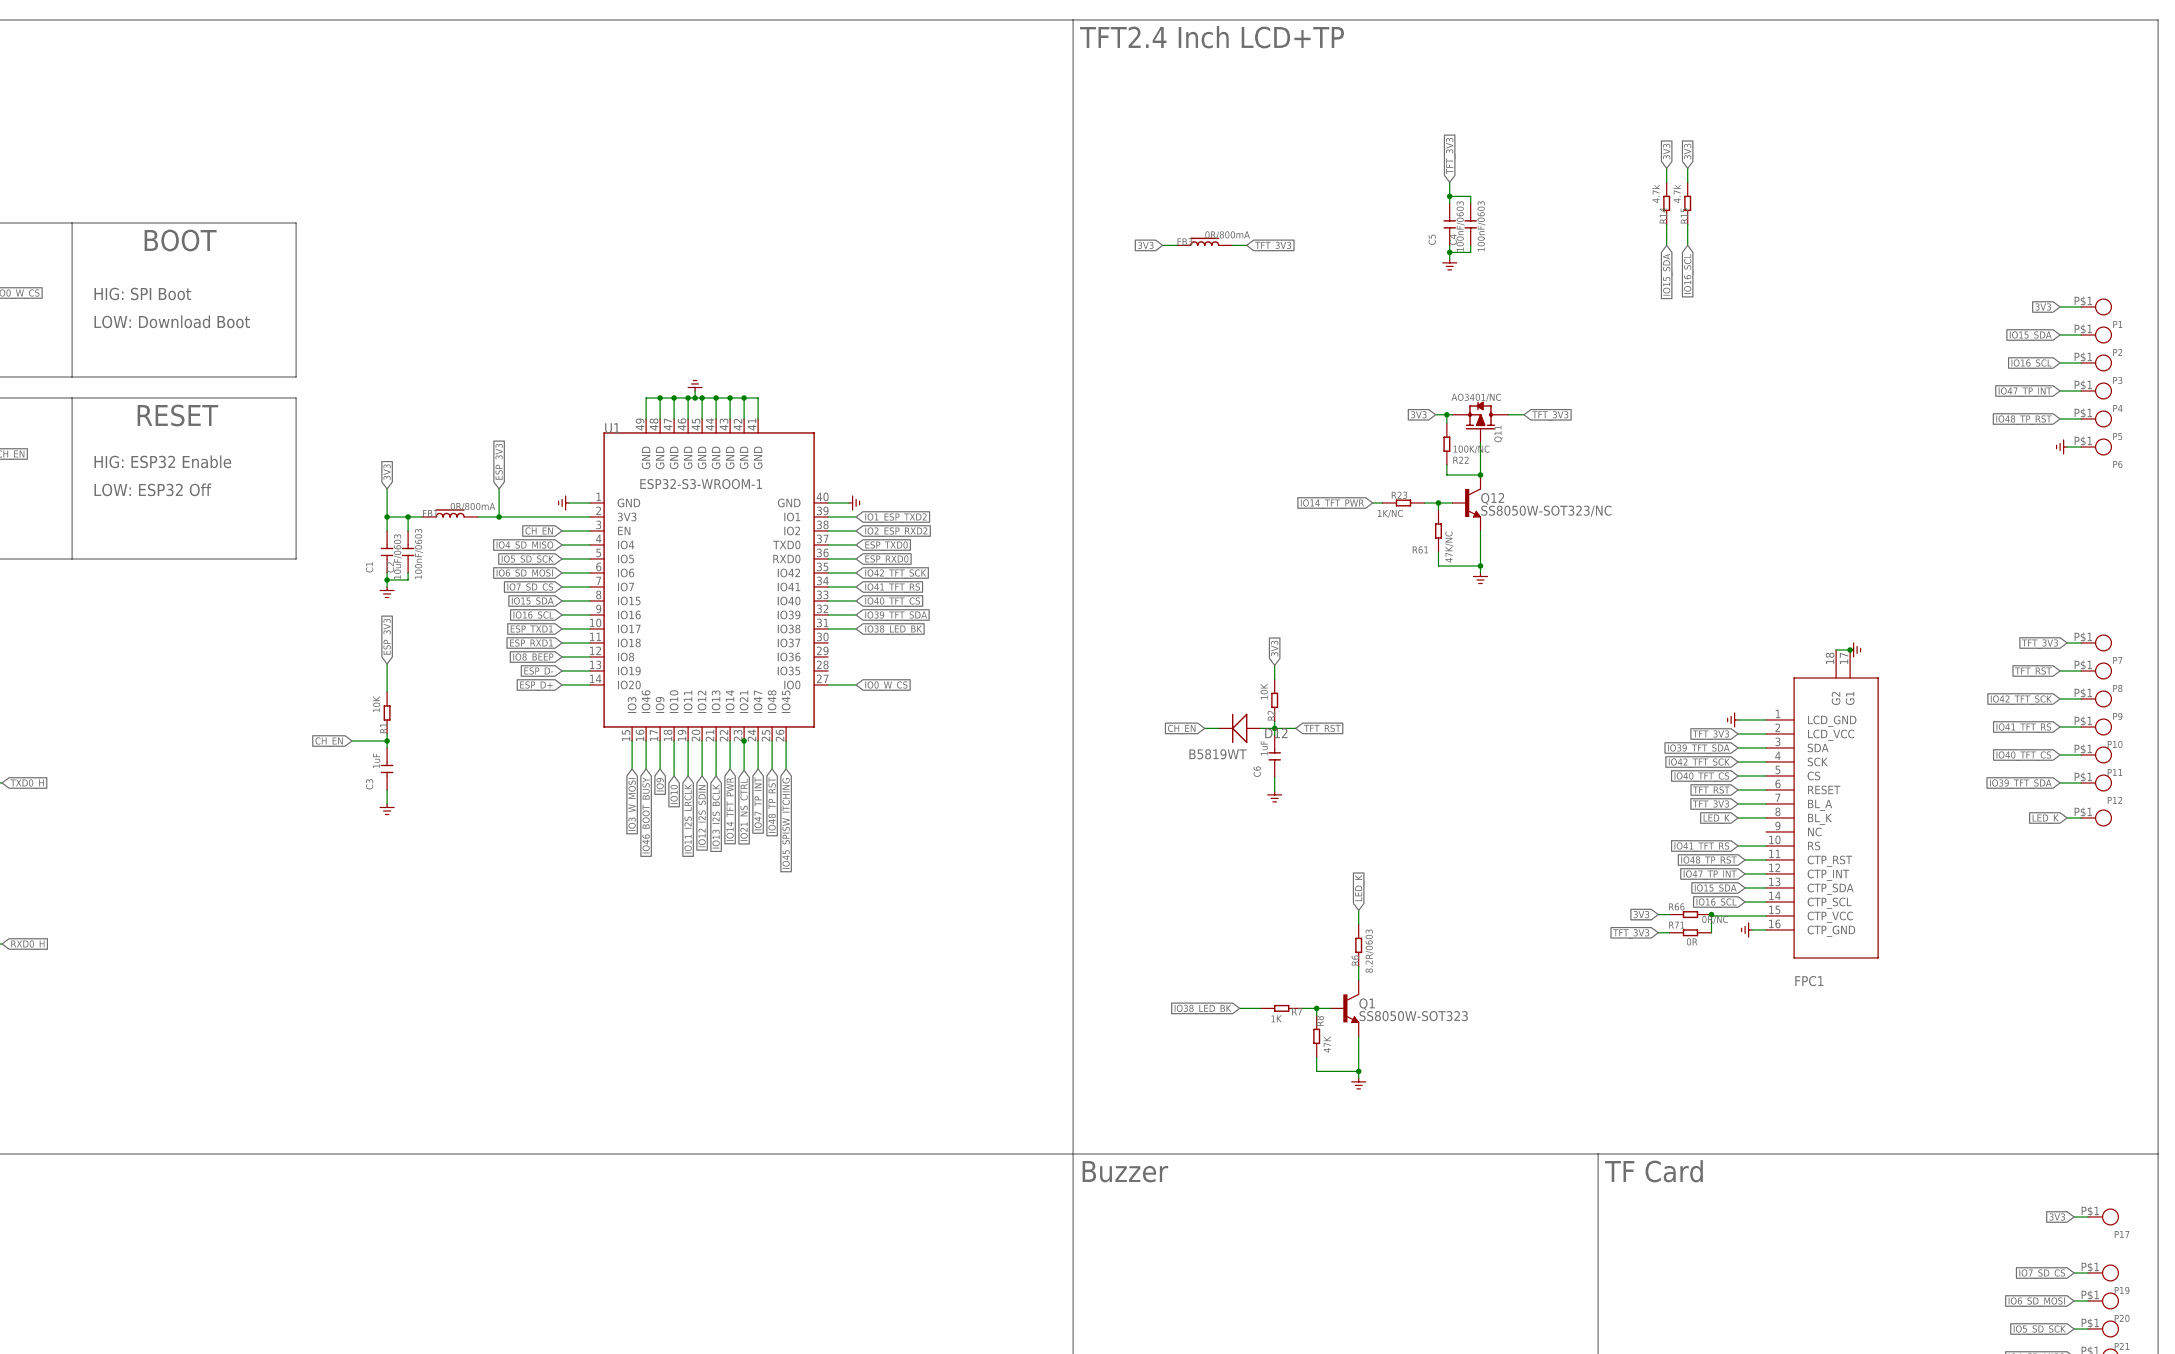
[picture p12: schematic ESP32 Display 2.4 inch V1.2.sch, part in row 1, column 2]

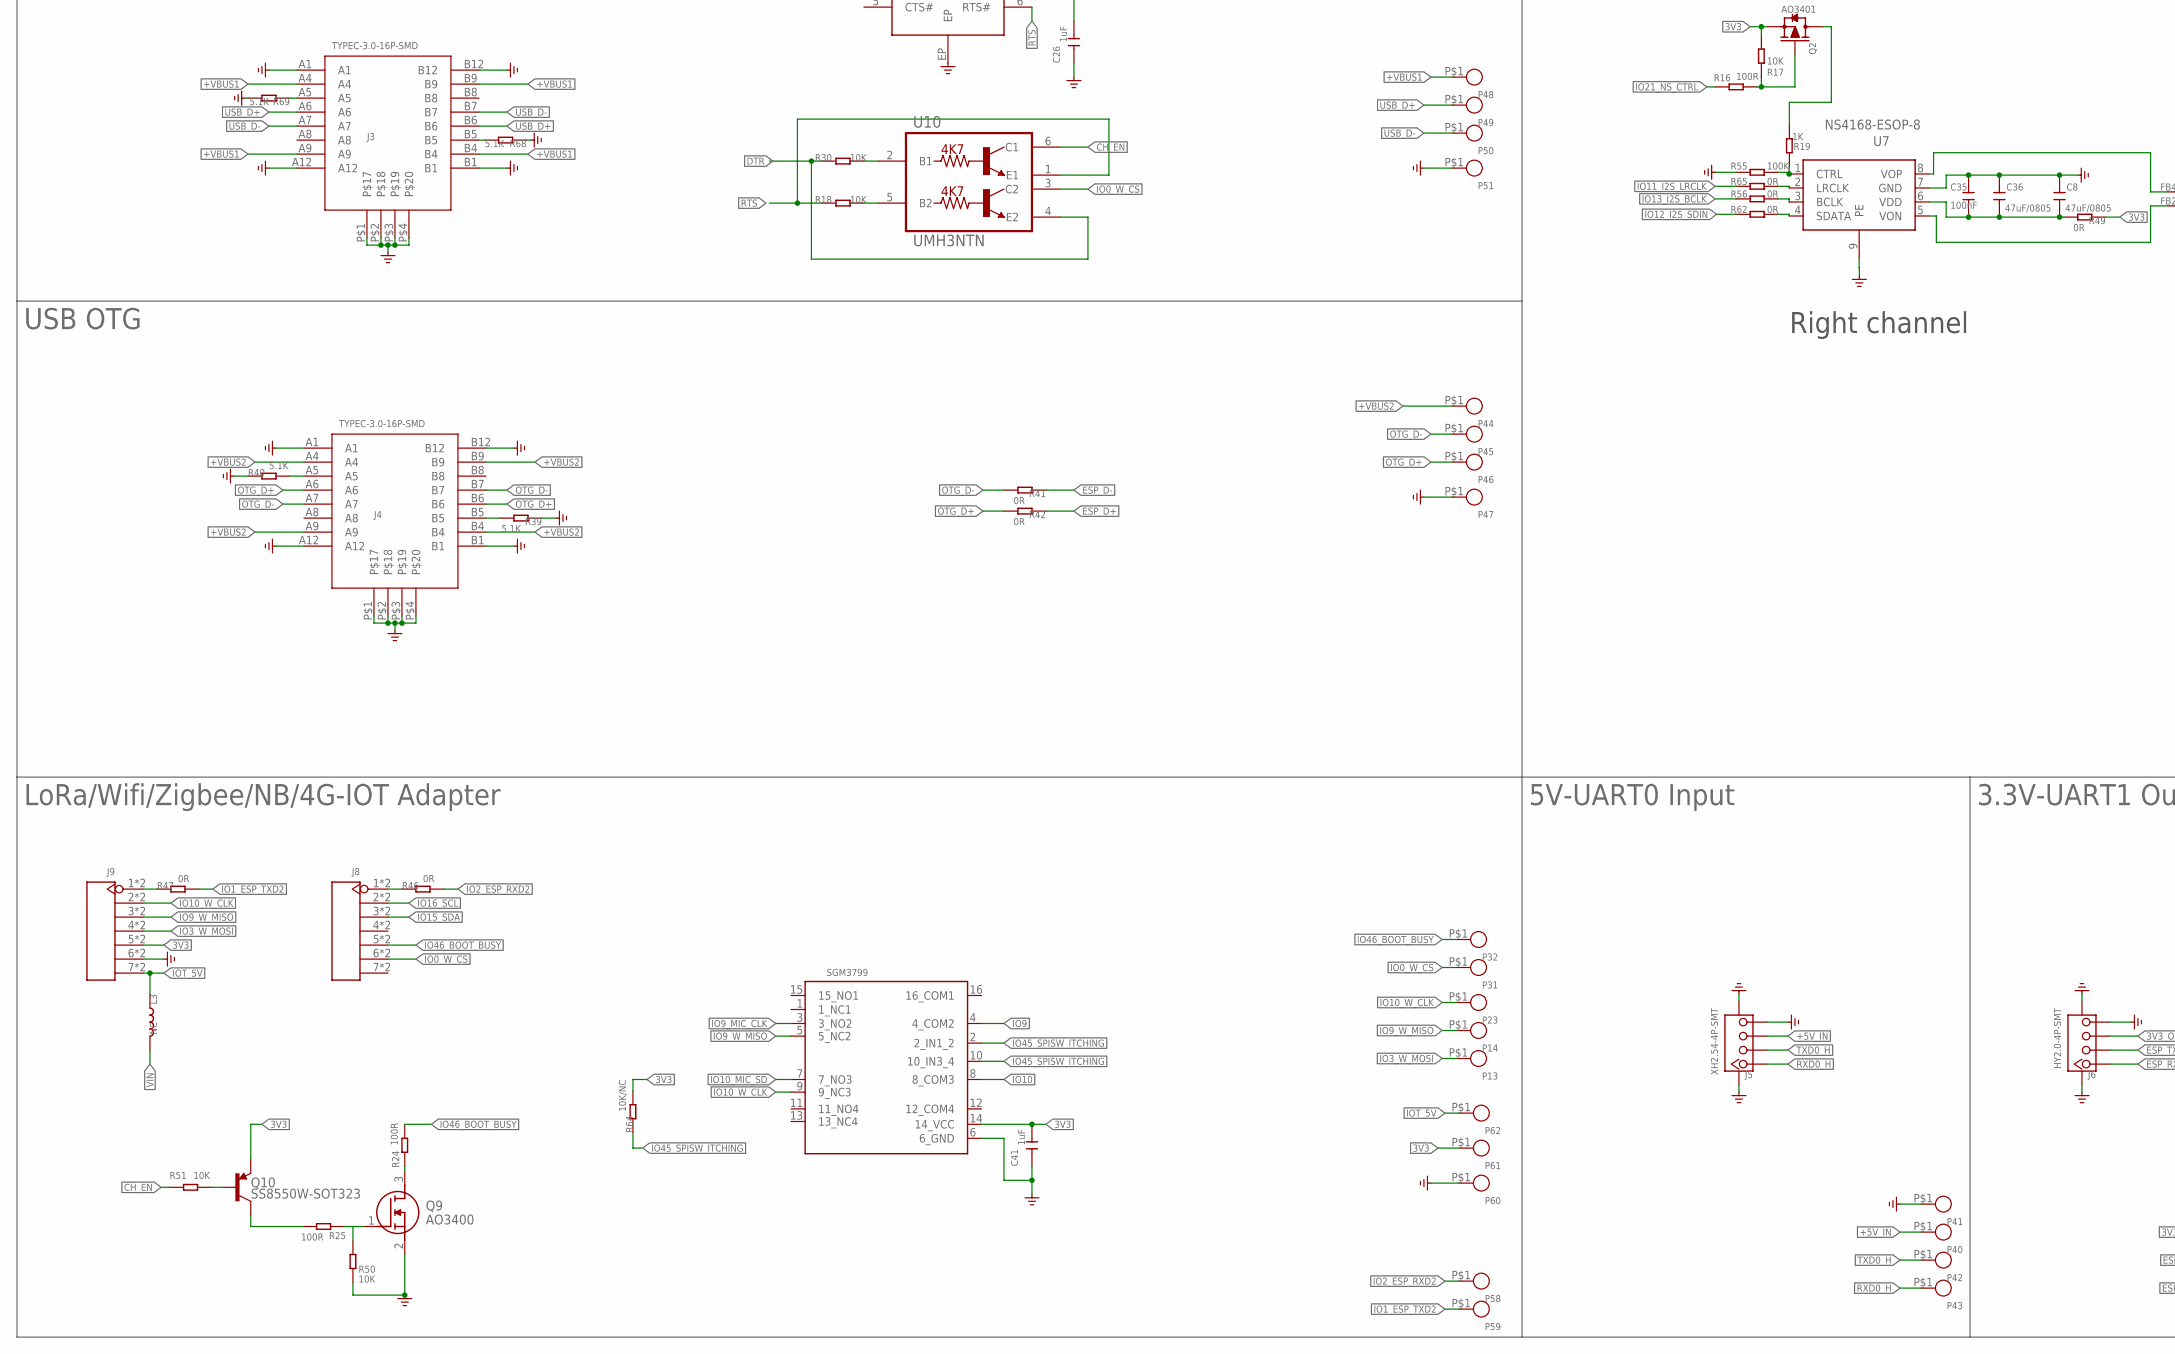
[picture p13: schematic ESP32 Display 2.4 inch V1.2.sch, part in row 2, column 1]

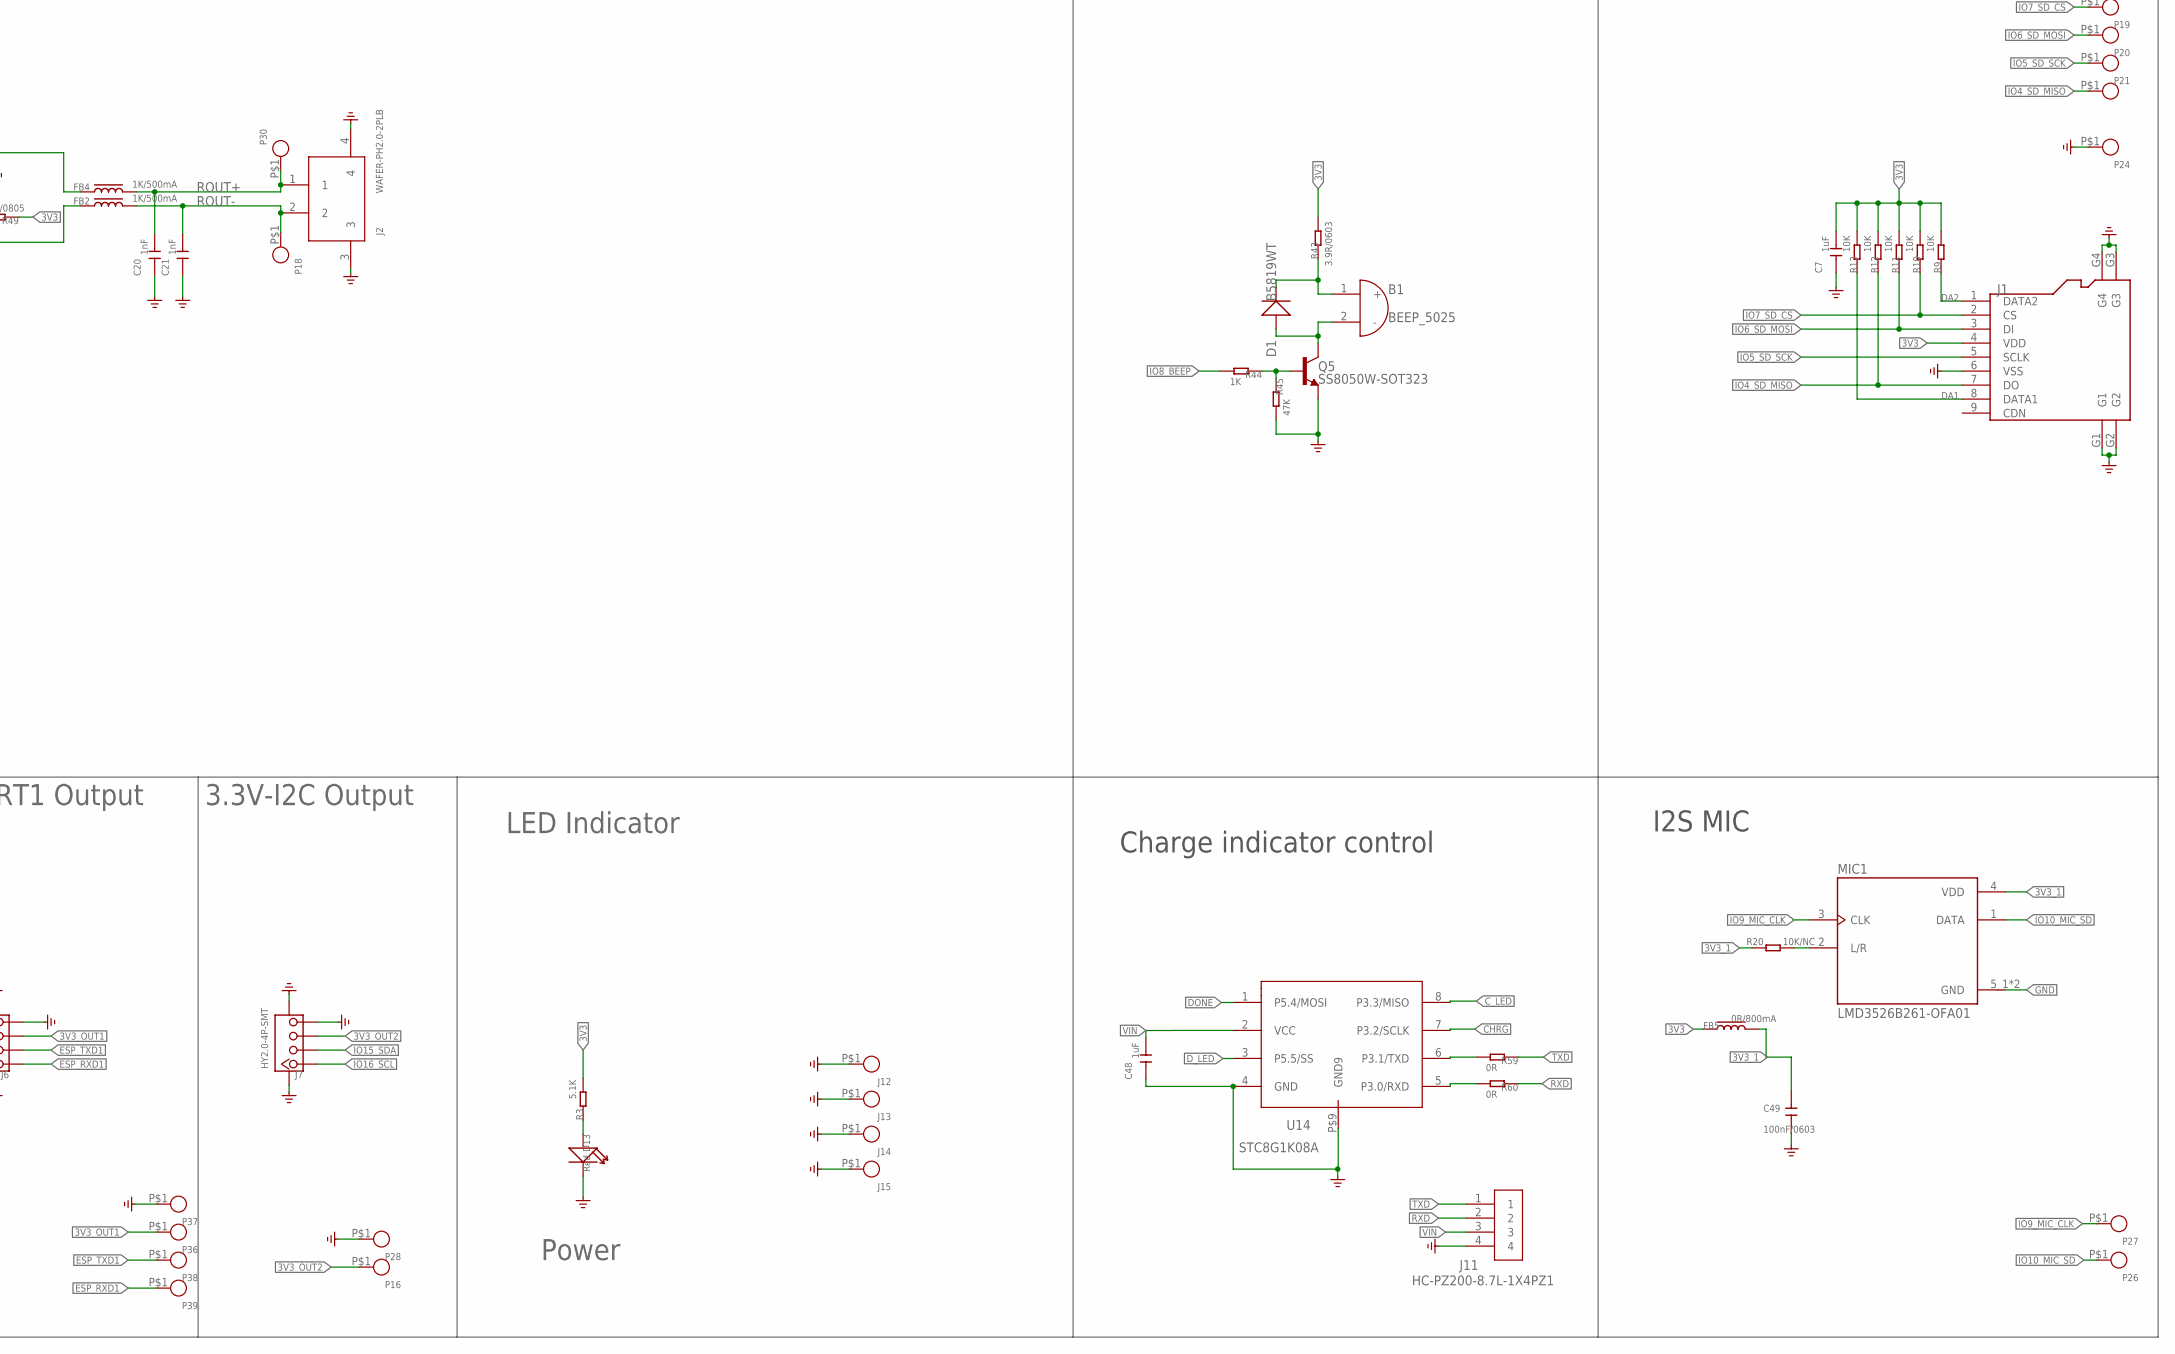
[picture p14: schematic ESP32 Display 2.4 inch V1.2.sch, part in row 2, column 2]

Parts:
B1: BEEP_5025
C1: 10uF/0603; C0603
C2, C4, C5, C49: 100nF/0603; C0603
C3, C6, C7, C26, C27, C41, C48: 1uF; C0402
C8, C36: 47uF/0805; C0805
C20, C21: 1nF; C0402
C28, C33, C34: 1uF/0603; C0603
C29: 10uF/0603/NC; C0603
C30, C31, C32: 22uF/0805; C0805
C35: 100nF; C0402
D1, D12: B5819WT; D_SOD523
D2: KT-0603RYG; LED_KT-0603RYG
D3, D5, D7: 1N5817WS; D_SOD323
D6, D8, D9: DSS34; D_SOD123FL
D13: Red; LED0603
FB1, FB3, FB5: 0R/800mA; L0603
FB2, FB4: 1K/500mA; L0603
FPC1: TFT-2.4-SPI-16P; FPC-0.5MM-16P-SMD
J1: HOLDER-MICROSD-9P; 9P-SMD-W/-RING
J2: WAFER-PH2.0-2PLB; CONN-TH_2P-P2.00_XUNPU_WAFER-PH2.0-2PLB
J3, J4: TYPEC-3.0-16P-SMD; USB-3.0TYPEC-SMD
J5: XH2.54-4P-SMT; XH2.54-4P-SMD
J6, J7: HY2.0-4P-SMT; CONNECTOR_4P-SMD-2.0
J8, J9: HEADER-7P-18.28X2.5; H7-2.54-18.28X2.5X5MM
J10: PH2.0WT-2PIN
J11: HC-PZ200-8.7L-1X4PZ1; TEST-PIN-4-2.0MM
J12, J13, J14, J15: THO-M3.25MM-HOLE; THO-M3.2*5MM-HOLE
K1, K2: BUTTON; 157SW
L1: 4.7uH/3A; L0420
L3: NC; L0603
MIC1: LMD3526B261-OFA01; MIC-SMD_5P-L3.5-W2.7-P1.67
P1, P2, P3, P4, P5, P6, P7, P8, P9, P10, P11, P12, P13, P14, P15, P16, P17, P18, P19, P20, P21, P22, P23, P24, P26, P27, P28, P30, P31, P32, P36, P37, P38, P39, P40, P41, P42, P43, P44, P45, P46, P47, P48, P49, P50, P51, P52, P53, P54, P55, P58, P59, P60, P61, P62: TEST_PADPAD-1.5MM; TEST_PAD-1.5MM
Q1, Q5: SS8050W-SOT323; MOS_SOT323
Q2, Q6, Q7, Q8: AO3401; PMOS_SOT23
Q3, Q4: BSS138W_SOT323; MOS_SOT323
Q9: AO3400; SOT95P280X125-3N
Q10: SS8550W-SOT323; MOS_SOT323
Q11: AO3401/NC; PMOS_SOT23
Q12: SS8050W-SOT323/NC; MOS_SOT323
R1, R2, R9, R10, R11, R12, R13, R17, R18, R30, R50, R51, R53, R54, R63, R67: 10K; R0402
R3, R5, R37, R39, R40, R57, R58, R68, R69: 5.1K; R0402
R4, R29: 2K; R0402
R6: 8.2R/0603; R0603-SP
R7, R19, R44: 1K; R0402
R8, R45: 47K; R0402
R14, R15, R31, R32, R33, R34: 4.7k; R0402
R16, R24, R25: 100R; R0402
R20, R64: 10K/NC; R0402
R22: 100K/NC; R0402
R23: 1K/NC; R0402
R27, R28, R35, R36, R41, R42, R46, R47, R49, R56, R59, R60, R62, R65, R71: 0R; R0402
R38, R48: NC; R0402
R43: 3.9R/0603; R0603-SP
R52: 45.3K; R0402
R55: 100K; R0402
R61: 47K/NC; R0402
R66: 0R/NC; R0402
U1: ESP32-S3-WROOM-1; ESP32-S3-WROOM-1-SMD41
U4: CH340K; ESOP-10-EP-150MIL
U5: TP4059-SOT23-6; SOT23-6L
U6: RY3420; IC_SOT23-5
U7: NS4168-ESOP-8
U8: SGM3799; IC_SGM3799_TQFN2.6X1.8_16L
U10: UMH3NTN; SOP65P210X100-6N
U14: STC8G1K08A; DFN8

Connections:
3V3: C1.2, C2.2, C7.2, C31.2, C32.2, C33.2, C41.2, FB1.1, FB3.1, FB5.1, J1.4 (VDD), J9.5, J9.5-5 (5), L1.2, P1.P$1, P17.P$1, P61.P$1, Q2.2 (S), Q3.1 (G), Q4.1 (G), Q7.2 (S), Q8.2 (S), Q10.2 (E), Q11.2 (S), R2.2, R3.2, R9.2, R10.2, R11.2, R12.2, R13.2, R14.2, R15.2, R17.2, R22.2, R31.2, R33.2, R43.2, R49.1, R52.2, R64.2, R66.2, U8.14 (14_VCC)
3V3_1: C49.2, FB5.2, MIC1.4 (VDD), R20.2
3V3_OUT1: J6.3, P36.P$1, Q8.3 (D)
3V3_OUT2: J7.3, P16.P$1, Q7.3 (D)
+5V_IN: D6.+, D7.+, J5.3, P40.P$1
+VBUS1: C26.2, D3.+, D9.+, J3.A4, J3.A9, J3.B4, J3.B9, P48.P$1, U4.7 (VCC)
+VBUS2: D5.+, D8.+, J4.A4, J4.A9, J4.B4, J4.B9, P44.P$1
+VC_IN: C28.2, D2.1, D2.2, D3.-, D5.-, D7.-, Q6.1 (G), R5.2, R54.2, R57.1, R58.1, U5.4 (VCC)
CHRG: R48.1, R57.2, U5.1 (CHG), U14.7 (P3.2/SCLK)
CH_EN: C3.2, D12.-, K2.2, R1.1, R51.1, U1.3 (EN), U10.6 (C1)
C_LED: R37.1, U14.8 (P3.3/MISO)
DA1: J1.8 (DATA1), R13.1
DA2: J1.1 (DATA2), R9.1
DONE: R38.1, R58.2, U5.5 (STD), U14.1 (P5.4/MOSI)
DTR: R30.2, U4.4 (DTR#), U10.4 (E2)
D_LED: R29.1, U14.3 (P5.5/SS)
ESP_3V3: FB1.2, R1.2, U1.2 (3V3)
ESP_D+: R42.1, U1.14 (IO20)
ESP_D-: R41.1, U1.13 (IO19)
ESP_RXD0: Q4.2 (S), R33.1, U1.36 (RXD0)
ESP_RXD1: J6.1, P39.P$1, U1.11 (IO18)
ESP_TXD0: Q3.2 (S), R31.1, U1.37 (TXD0)
ESP_TXD1: J6.2, P38.P$1, U1.10 (IO17)
GND: C1.1, C2.1, C3.1, C4.1, C5.1, C6.1, C7.1, C8.2, C20.1, C21.1, C26.1, C27.1, C28.1, C29.1, C30.1, C31.1, C32.1, C33.1, C34.1, C35.2, C36.2, C41.1, C48.1, C49.1, D13.-, FPC1.1 (LCD_GND), FPC1.16 (CTP_GND), FPC1.17 (G1), FPC1.18 (G2), J1.6 (VSS), J1.G1, J1.G2, J1.G3, J1.G4, J2.3, J2.4, J3.A1, J3.A12, J3.B1, J3.B12, J3.P$1, J3.P$2, J3.P$3, J3.P$4, J4.A1, J4.A12, J4.B1, J4.B12, J4.P$1, J4.P$2, J4.P$3, J4.P$4, J5.4, J5.5 (SS1), J5.6 (SS2), J6.4, J6.SS1, J6.SS2, J7.4, J7.SS1, J7.SS2, J9.6, J9.6-6 (6), J10.P$2, J10.P$3, J10.P$4, J11.4, J12.P$1, J13.P$1, J14.P$1, J15.P$1, K1.1, K2.1, MIC1.5_1 (GND), MIC1.5_2 (GND), P6.P$1, P24.P$1, P28.P$1, P37.P$1, P41.P$1, P47.P$1, P51.P$1, P53.P$1, P55.P$1, P60.P$1, Q1.2 (E), Q5.2 (E), Q9.2 (S), Q12.2 (E), R4.1, R8.2, R39.1, R40.1, R45.2, R50.2, R53.1, R54.1, R55.2, R61.2, R63.1, R67.1, R68.1, R69.2, U1.1 (GND), U1.40 (GND), U1.41 (GND), U1.42 (GND), U1.43 (GND), U1.44 (GND), U1.45 (GND), U1.46 (GND), U1.47 (GND), U1.48 (GND), U1.49 (GND), U4.3 (GND), U4.EP, U5.2 (GND), U6.2 (GND), U7.7 (GND), U7.9 (PE), U8.6 (6_GND), U14.4 (GND), U14.P$9 (GND9)
IO0_W_CS: J8.6, J8.6-6 (6), K1.2, P31.P$1, U1.27 (IO0), U10.3 (C2)
IO1_ESP_TXD2: P59.P$1, R47.2, U1.39 (IO1)
IO2_ESP_RXD2: P58.P$1, R46.2, U1.38 (IO2)
IO3_W_MOSI: J9.4, J9.4-4 (4), P13.P$1, U1.15 (IO3)
IO4_SD_MISO: J1.7 (DO), P22.P$1, R12.1, U1.4 (IO4)
IO5_SD_SCK: J1.5 (SCLK), P21.P$1, U1.5 (IO5)
IO6_SD_MOSI: J1.3 (DI), P20.P$1, R11.1, U1.6 (IO6)
IO7_SD_CS: J1.2 (CS), P19.P$1, R10.1, U1.7 (IO7)
IO8_BEEP: R44.2, U1.12 (IO8)
IO9: U1.17 (IO9), U8.4 (4_COM2)
IO9_MIC_CLK: MIC1.3 (CLK), P27.P$1, U8.3 (3_NO2)
IO9_W_MISO: J9.3, J9.3-3 (3), P14.P$1, U8.5 (5_NC2)
IO10: U1.18 (IO10), U8.8 (8_COM3)
IO10_MIC_SD: MIC1.1 (DATA), P26.P$1, U8.7 (7_NO3)
IO10_W_CLK: J9.2, J9.2-2 (2), P23.P$1, U8.9 (9_NC3)
IO11_I2S_LRCLK: R65.2, U1.19 (IO11)
IO12_I2S_SDIN: R62.2, U1.20 (IO12)
IO13_I2S_BCLK: R56.2, U1.21 (IO13)
IO14_TFT_PWR: R23.2, U1.22 (IO14)
IO15_SDA: FPC1.13 (CTP_SDA), J7.2, J8.3, J8.3-3 (3), P2.P$1, R14.1, U1.8 (IO15)
IO16_SCL: FPC1.14 (CTP_SCL), J7.1, J8.2, J8.2-2 (2), P3.P$1, R15.1, U1.9 (IO16)
IO21_NS_CTRL: R16.1, U1.23 (IO21)
IO38_LED_BK: R7.2, U1.31 (IO38)
IO39_TFT_SDA: FPC1.3 (SDA), P12.P$1, U1.32 (IO39)
IO40_TFT_CS: FPC1.5 (CS), P11.P$1, U1.33 (IO40)
IO41_TFT_RS: FPC1.10 (RS), P10.P$1, U1.34 (IO41)
IO42_TFT_SCK: FPC1.4 (SCK), P9.P$1, U1.35 (IO42)
IO45_SPISW_ITCHING: R64.1, U1.26 (IO45), U8.2 (2_IN1_2), U8.10 (10_IN3_4)
IO46_BOOT_BUSY: J8.5, J8.5-5 (5), P32.P$1, R24.2, U1.16 (IO46)
IO47_TP_INT: FPC1.12 (CTP_INT), P4.P$1, U1.24 (IO47)
IO48_TP_RST: FPC1.11 (CTP_RST), P5.P$1, U1.25 (IO48)
IOT_5V: J9.7, J9.7-7 (7), L3.1, P62.P$1
LED_K: FPC1.8 (BL_K), P15.P$1, R6.2
unnamed: Q1.3 (C), R6.1
unnamed: D13.+, R3.1
unnamed: Q1.1 (B), R7.1, R8.1
unnamed: R59.2, U14.6 (P3.1/TXD)
unnamed: R60.2, U14.5 (P3.0/RXD)
unnamed: FB4.1, U7.8 (VOP)
unnamed: FB2.1, U7.5 (VON)
unnamed: MIC1.2 (L/R), R20.1
unnamed: Q2.1 (G), R16.2, R17.1
unnamed: R4.2, U5.6 (PRO)
unnamed: FPC1.15 (CTP_VCC), R66.1, R71.1
unnamed: Q12.1 (B), R23.1, R61.1
unnamed: Q9.1 (G), R25.1, R50.1
unnamed: R27.1, U4.1 (UD+)
unnamed: R28.1, U4.2 (UD-)
unnamed: L1.1, U6.3 (SW)
unnamed: R30.1, U10.2 (B1)
unnamed: R18.1, U10.5 (B2)
unnamed: Q8.1 (G), R63.2
unnamed: C27.2, U4.10 (V3)
unnamed: Q7.1 (G), R67.2
unnamed: R35.2, U4.9 (RXD)
unnamed: R36.2, U4.8 (TXD)
unnamed: J9.1, J9.1-1 (1), R47.1
unnamed: J4.B5, R39.2
unnamed: J4.A5, R40.2
unnamed: Q5.1 (B), R44.1, R45.1
unnamed: B1.2 (-), D1.+, Q5.3 (C)
unnamed: B1.1 (+), D1.-, R43.1
unnamed: J3.B5, R68.2
unnamed: R52.1, R53.2, U6.5 (FB)
unnamed: J3.A5, R69.1
unnamed: Q10.3 (C), R25.2
unnamed: Q10.1 (B), R51.2
unnamed: Q11.1 (G), Q12.3 (C), R22.1
unnamed: J8.1, J8.1-1 (1), R46.1
unnamed: R65.1, U7.2 (LRCLK)
unnamed: D2.3, R29.2, R38.2
unnamed: D2.4, R37.2, R48.2
unnamed: R56.1, U7.3 (BCLK)
unnamed: R62.1, U7.4 (SDATA)
unnamed: C8.1, C35.1, C36.1, R49.2, U7.6 (VDD)
unnamed: Q9.3 (D), R24.1
NS_3V3: Q2.3 (D), R19.1
NS_CTRL: R19.2, R55.1, U7.1 (CTRL)
OTG_D+: J4.A6, J4.B6, P46.P$1, R42.2
OTG_D-: J4.A7, J4.B7, P45.P$1, R41.2
ROUT+: C20.2, FB4.2, J2.1, P30.P$1
ROUT-: C21.2, FB2.2, J2.2, P18.P$1
RTS: R18.2, U4.6 (RTS#), U10.1 (E1)
RXD: J11.2, R60.1
RXD0_H: J5.1, P43.P$1, Q4.3 (D), R34.1, R36.1
TFT_3V3: C4.2, C5.2, FB3.2, FPC1.2 (LCD_VCC), FPC1.7 (BL_A), P7.P$1, Q11.3 (D), R71.2
TFT_RST: C6.2, D12.+, FPC1.6 (RESET), P8.P$1, R2.1
TXD: J11.1, R59.1
TXD0_H: J5.2, P42.P$1, Q3.3 (D), R32.1, R35.1
USB_D+: J3.A6, J3.B6, P49.P$1, R27.2
USB_D-: J3.A7, J3.B7, P50.P$1, R28.2
VBAT: C29.2, J10.P$1, P52.P$1, Q6.3 (D), R5.1, U5.3 (BAT)
VIN: C30.2, C34.2, C48.2, D6.-, D8.-, D9.-, J11.3, L3.2, P54.P$1, Q6.2 (S), R32.2, R34.2, U6.1 (EN), U6.4 (VIN), U14.2 (VCC)

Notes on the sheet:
DC-DC Step Down
Battery Power Management
USB TO UART0
USB OTG
LoRa/Wifi/Zigbee/NB/4G-IOT Adapter
5V-UART0 Input
3.3V-UART1 Output
3.3V-I2C Output
Power Amplifier
ESP32 S3 Mini System
TFT2.4 Inch LCD+TP
Buzzer
TF Card
LED Indicator
BOOT
RESET
HIG: SPI Boot
LOW: Download Boot
HIG: ESP32 Enable
LOW: ESP32 Off
Power
Right channel
Charge indicator control
I2S MIC

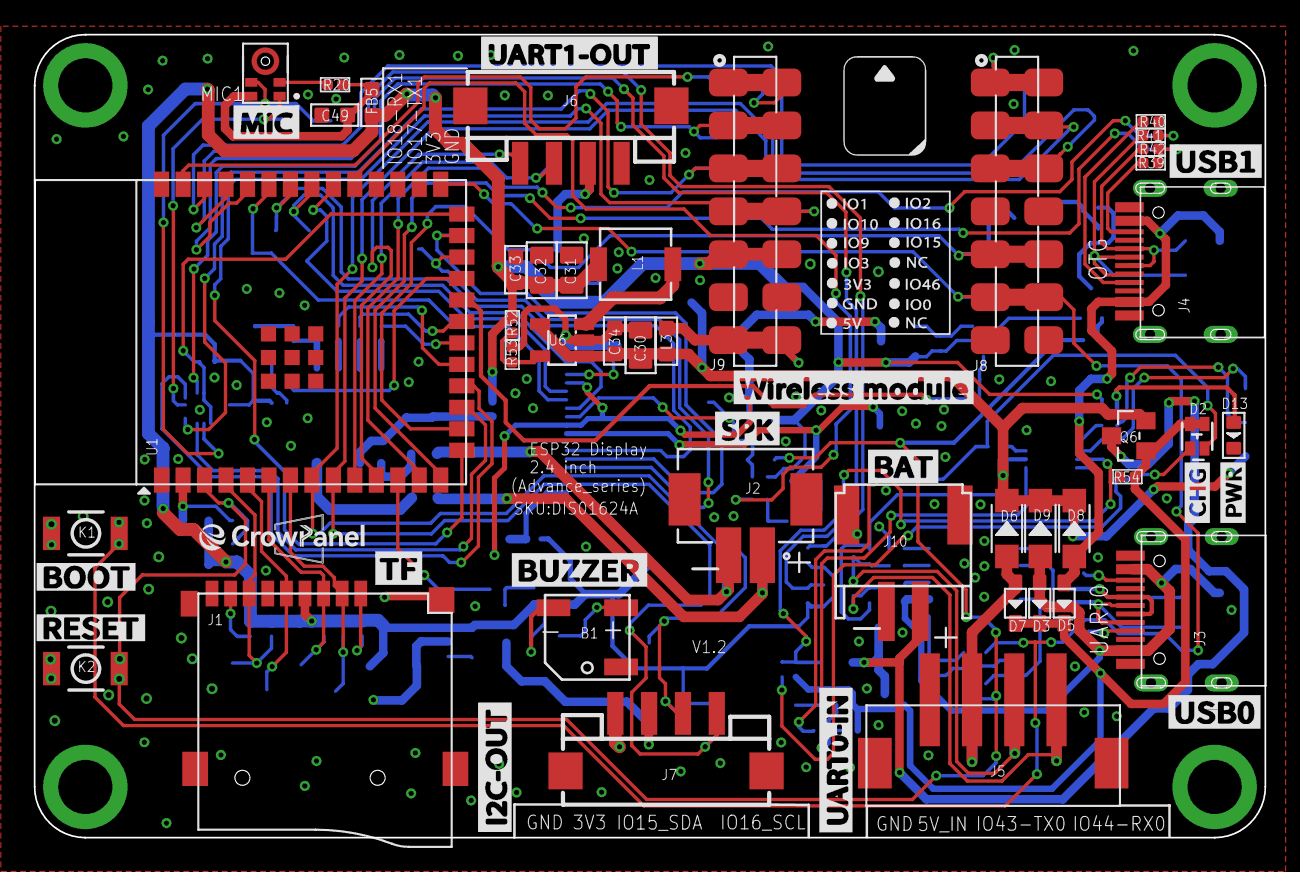
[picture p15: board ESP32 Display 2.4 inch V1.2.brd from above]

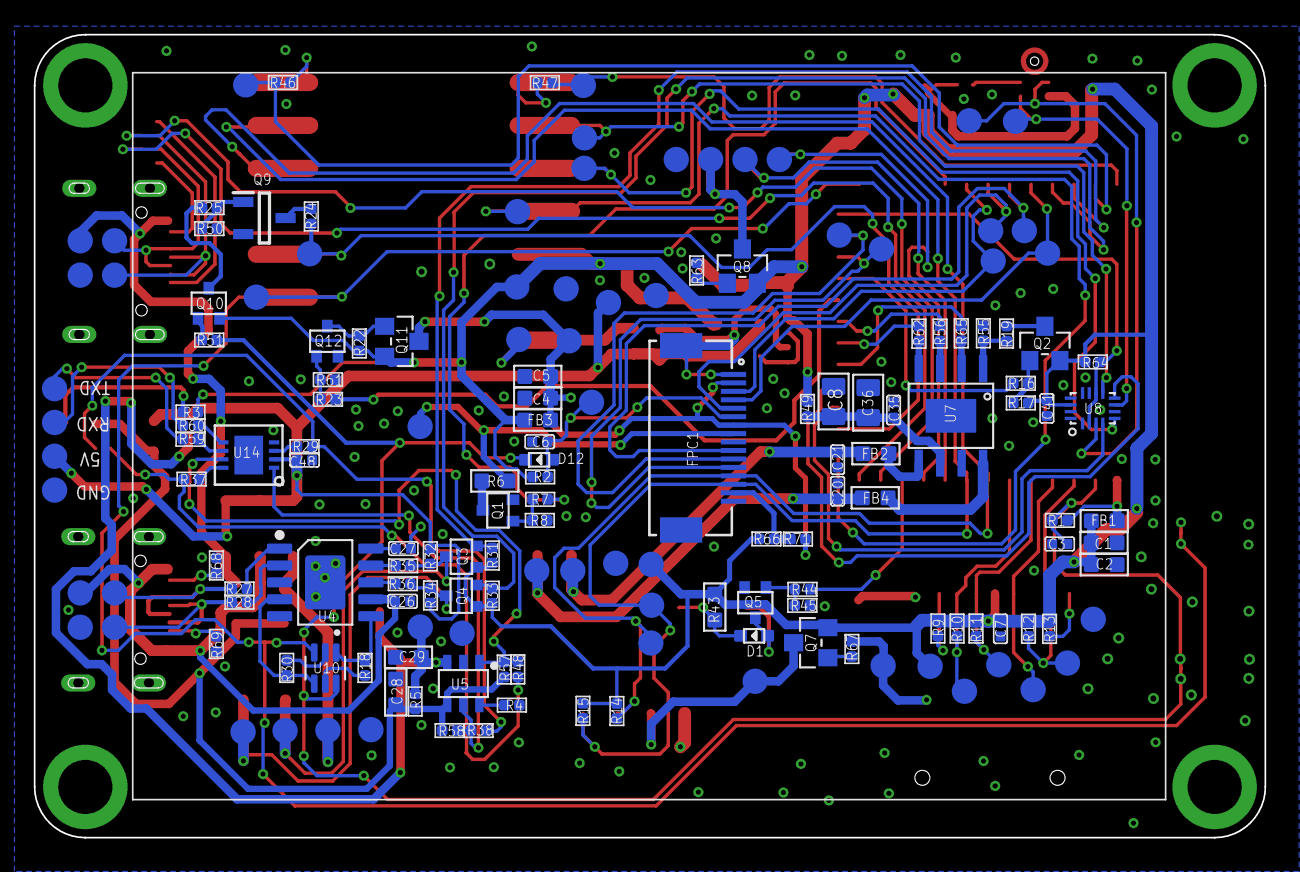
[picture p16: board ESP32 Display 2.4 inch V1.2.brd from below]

Board: 2 copper layers, 72.8 x 47.5 mm, 204 parts (158 on the bottom side), 117 nets.

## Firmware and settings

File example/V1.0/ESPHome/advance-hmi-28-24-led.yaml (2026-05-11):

esphome:
  name: advance-hmi-28-24-led
  friendly_name: Advance_HMI_28_24_LED
  platformio_options:
     build_flags: "-DBOARD_HAS_PSRAM"
     board_build.esp-idf.memory_type: qio_opi
     board_build.flash_mode: dio
esp32:
  board: esp32-s3-devkitc-1
  framework:
    type: esp-idf
    sdkconfig_options:
      CONFIG_ESP32S3_DEFAULT_CPU_FREQ_240: y
      CONFIG_ESP32S3_DATA_CACHE_64KB: y
      CONFIG_SPIRAM_FETCH_INSTRUCTIONS: y
      CONFIG_SPIRAM_RODATA: y

psram:
  mode: octal
  speed: 80MHz 

# Enable logging
logger:

# Enable Home Assistant API
api:
  encryption:
    key: "KsooeSPHrufNtxgcm86uqEYcka1CF1HbXCCm2e7lmKw="

ota:
  - platform: esphome
    password: "b7090bfe3cf91360b3bad2ab078c66d9"

wifi:
  ssid: !secret wifi_ssid
  password: !secret wifi_password

  # Enable fallback hotspot (captive portal) in case wifi connection fails
  ap:
    ssid: "Advance-Hmi-28-24-Led"
    password: "0eQTw80dDbOw"

captive_portal:

output:
  - platform: ledc
    pin: GPIO38
    inverted: False
    id: backlight_pwm

# Define a monochromatic, dimmable light for the backlight
light:
  - platform: monochromatic
    output: backlight_pwm
    name: "Display Backlight"
    id: back_light
    restore_mode: ALWAYS_ON

color:
  - id: my_red
    red: 100%
    green: 0%
    blue: 0%
  - id: my_white
    red: 100%
    green: 100%
    blue: 100%
  - id: my_green
    red: 0%
    green: 100%
    blue: 0%
  - id: my_blue
    red: 0%
    green: 0%
    blue: 100%
  - id: my_black
    red: 0%
    green: 0%
    blue: 0%

image:
  - file: "small_hum.png"
    id: small_hum
    resize: 50x75
    type: RGB565
  - file: "small_logo.png"
    id: small_logo
    resize: 200x200
    type: RGB565
    transparency: chroma_key
  - file: "small_temp.png"
    id: small_temp
    resize: 50x75
    type: RGB565

i2c:
  sda: 17
  scl: 18
  scan: true

sensor:
  - platform: aht10
    variant: AHT20
    temperature:
      name: "Room Temperature"
      id: room_temp
      unit_of_measurement: "°C"
      accuracy_decimals: 1
    humidity:
      name: "Room Humidity"
      id: room_hum
      unit_of_measurement: "%"
      accuracy_decimals: 1
    update_interval: 1s

spi:
  clk_pin: 42
  mosi_pin: 39
display:
  - platform: st7789v
    id: main_display
    model: Custom 
    height: 320
    offset_height: 0
    width: 240
    offset_width: 0
    rotation: 90
    cs_pin: GPIO40
    dc_pin: GPIO41
    reset_pin: GPIO3
     
        

lvgl:
  log_level: INFO
  color_depth: 16
  bg_color: 0xFFFFFF
  text_font: montserrat_14
  widgets:
    - image:
        id: lvgl_logo
        src: small_logo
        x: 25
        y: 10
    - image:
        id: lvgl_temp
        src: small_temp
        x: 50
        y: 125
    - image:
        id: lvgl_hum
        src: small_hum
        x: 200
        y: 125

    - label:
        id: label_temp
        x: 30
        y: 200
        text: "Temp: --°C"
    - label:
        id: label_hum
        x: 180
        y: 200
        text: "Humi: --%"


interval:
  - interval: 1s
    then:
      - lambda: |-
          char temp_str[20];
          char hum_str[20];
          snprintf(temp_str, sizeof(temp_str), "Temp: %.1f°C", id(room_temp).state);
          snprintf(hum_str, sizeof(hum_str), "Humi: %.1f%%", id(room_hum).state);
          lv_label_set_text(id(label_temp), temp_str);
          lv_label_set_text(id(label_hum), hum_str);

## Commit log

2026-04-28 sync example/
    [Wireless Modular Burn Board.brd, Wireless Modular Burn Board.sch, Wireless Module ESP32-H2 V1.0.brd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]
2026-08-03 更新代码 2026-08-03 12:06
    [Wireless Modular Burn Board.brd, Wireless Modular Burn Board.sch, Wireless Module ESP32-H2 V1.0.brd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]
